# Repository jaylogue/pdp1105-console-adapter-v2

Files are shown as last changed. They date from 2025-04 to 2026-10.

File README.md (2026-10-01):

# PDP-11/05 Console Adapter

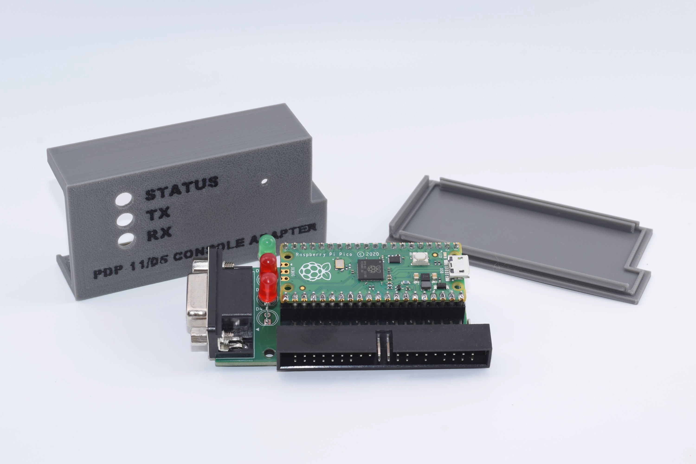
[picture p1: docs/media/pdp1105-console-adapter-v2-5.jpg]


The *PDP-11/05 Console Adapter* is a hardware device which acts as a USB and RS-232 serial interface to the console of a [PDP-11/05](http://gunkies.org/wiki/PDP-11/05) minicomputer. The Console Adapter provides a number of useful features for working with the PDP-11/05:

- **Direct connection to the SCL connector on the back of the PDP-11/05**
- **USB-to-serial functionality, allowing access to the PDP-11 console from a modern terminal program**
- **Auxiliary RS-232 interface for connecting a real serial terminal**
- **External baud clock generator, allowing console data rates greater than 2400 bps**
- **Dynamically adjustable serial data rate and format (110 to 38400 bps, 8-N-2, 7-E-2, 7-O-2)**
- **Virtual paper tape reader compatible with the 11/05's READER RUN signal**
- **M9312/M9301 console loader that can directly load data into the PDP-11's memory using console commands**

This version of the PDP-11/05 Console Adapter project (version 2) is based on the ubiquitous [Raspberry Pi Pico](https://www.raspberrypi.com/products/raspberry-pi-pico/) microcontroller. An earlier version based on the Teensy 3.2 microcontroller can be found [here](https://github.com/jaylogue/pdp-1105-console-usb-adapter).

### Project Status (2025/07/29)

The first major release of the PDP-11/05 Console Adapter is ready. The schematic and PCB designs are finished and final hardware has been built. The firmware is feature complete and tested, and user documentation has been written. Two different 3D-printed enclosures have been designed and built, and the design files for these are available for download.

I am happy to make assembled hardware or kits available to those enthusiasts who own real PDP-11/05 or /10 systems. Please reach out to me at jay DOT logue AT gmail DOT com for details.

<hr>

**[How it Works](#how-it-works)**<br>
&nbsp;&nbsp;&nbsp;&nbsp;&nbsp;&nbsp;&nbsp;&nbsp;**[Console Interface](#console-interface)**<br>
&nbsp;&nbsp;&nbsp;&nbsp;&nbsp;&nbsp;&nbsp;&nbsp;**[Auxiliary Terminal Interface](#auxiliary-terminal-interface)**<br>
&nbsp;&nbsp;&nbsp;&nbsp;&nbsp;&nbsp;&nbsp;&nbsp;**[Baud Clock Generation](#baud-clock-generation)**<br>
&nbsp;&nbsp;&nbsp;&nbsp;&nbsp;&nbsp;&nbsp;&nbsp;**[Host Selectable Data Rate / Serial Format](#host-selectable-data-rate--serial-format)**<br>
&nbsp;&nbsp;&nbsp;&nbsp;&nbsp;&nbsp;&nbsp;&nbsp;**[Status LEDs](#status-leds)**<br>
&nbsp;&nbsp;&nbsp;&nbsp;&nbsp;&nbsp;&nbsp;&nbsp;**[Power Source](#power-source)**<br>
&nbsp;&nbsp;&nbsp;&nbsp;&nbsp;&nbsp;&nbsp;&nbsp;**[Virtual Paper Tape Reader](#virtual-paper-tape-reader)**<br>
&nbsp;&nbsp;&nbsp;&nbsp;&nbsp;&nbsp;&nbsp;&nbsp;**[M9312/M9301 Console Loader](#m9312m9301-console-loader)**<br>
&nbsp;&nbsp;&nbsp;&nbsp;&nbsp;&nbsp;&nbsp;&nbsp;**[On-device File Library](#on-device-file-library)**<br>
&nbsp;&nbsp;&nbsp;&nbsp;&nbsp;&nbsp;&nbsp;&nbsp;**[XMODEM File Upload](#xmodem-file-upload)**<br>
**[Schematic](#schematic)**<br>
**[PCB Design Files](#pcb-design-files)**<br>
**[3D Printable Cases](#3d-printable-cases)**<br>
**[User Documentation](#user-documentation)**<br>
**[License](#license)**<br>

## How it Works

### Console Interface

At the most basic level, the Console Adapter operates as a TTL-serial interface, connecting the PDP-11's console (also known as the Serial Communication Line or SCL port) to one of the Pico's internal UARTs. Level shifting circuitry in the adapter adjusts the PDP's 5V outputs to match the Pico's 3.3V inputs. Using USB software on the Pico, the adapter appears as a virtual COM port when connected to a host computer via USB, making it possible to use a standard terminal program (e.g. minicom, picocom or PuTTY) to interact with the PDP's console. In this way, the Console Adapter operates very similarly to an off-the-shelf USB-to-TTL serial device, with the exception that its behavior is fully customizable in software.

The Console Adapter supports standard serial data rates in the range accepted by the PDP-11 (110 to 38400 bps). Internally, the CPU in the PDP-11/05 is hard-wired to use the 8-N-2 serial format. However, with appropriate software support on the PDP side, 7-E-2 or 7-O-2 formats can also be used (other formats are not supported). Based on this, the Console Adapter limits the SCL format to one of these three combinations.

### Baud Clock Generation

The PDP-11/05 CPU includes a clock generator circuit which is used to generate the 16X clock signal needed to drive the internal console UART chip. Due to its simplicity, the internal generator limits the maximum usable data rate to 2400 bps. Conveniently, the PDP-11/05 provides a way to override the internal generator by providing an external clock signal on the SCL port. This allows the console to run at substantially higher data rates (theoretically up to 40000 bps).

To enable higher data rates, the Console Adapter employs a PWM peripheral on the Pico to generate the necessary clock signal to drive the PDP's UART. The frequency of this clock signal is automatically adjusted to match the data rate of the Pico's UART, ensuring that the two systems are always in sync.

### Auxiliary Terminal Interface

In addition to the host USB interface, the Console Adapter provides a second interface which can be used to connect a traditional serial terminal such as a VT-100. An RS-232 level shifter (MAX3232) is used to convert the signals to standard EIA levels, allowing most terminals of the era to be used. When connected, the terminal functions as an additional console for the PDP-11.

An auxiliary terminal can be used in parallel with a terminal program connected via USB. When operated this way, characters typed on either the host computer or the auxiliary terminal are forwarded to the PDP-11, while characters output by the PDP-11 appear simultaneously on both terminals. It is also possible to use the Console Adapter with just an auxiliary terminal connected (i.e. without a host USB connection).

The data rate and serial format for the auxiliary terminal can be set independently from that of the PDP-11's SCL port. (Although, since neither interface supports flow control, it is best to keep the data rates the same or similar between the two.)

### Host Selectable Data Rate / Serial Format

The Console Adapter appears to the host computer as a standard USB COM device. As such, it is able to receive and process standard USB requests to change the serial configuration (also known as CDC Line Coding requests). This makes it possible to adjust the adapter's serial data rate and format directly from within terminal software running on the host.

When the Console Adapter receives a Line Coding request it adjusts the configuration of the console UART and baud clock generator to match the requested data rate and serial format. Serial configuration changes happen on the fly and can be made at any time. If desired, the auxiliary terminal interface can also be set to automatically adjust to the new configuration.

The PDP-11/05's SCL port is hard-wired to use 2 stop bits. This format is somewhat unusual in modern systems, and most terminal programs default to a format using 1 stop bit (usually 8-N-1). As a convenience to the user, the Console Adapter accepts USB Line Coding requests for 1 stop bit formats and internally translates them into the equivalent 2 stop bit format when configuring the SCL port.

The choice to dynamically adjust the serial configuration based on a request from the host can be enabled or disabled independently for both the SCL and auxiliary terminal ports. When this feature is disabled, the serial configuration is controlled by a setting in the Console Adapter's settings menu. These settings are persisted in flash and survive adapter reboots.

### Status LEDs

The PDP-11/05 Console Adapter has three status LEDs:

- **Power/Activity LED**: Lit while the system is powered. Flashes briefly whenever there is activity in the Console Adapter.
- **TX and RX LEDs**: Normally off. Flash on whenever characters are transmitted/received by the PDP-11.

Additionally, the Pico's onboard LED mimics the behavior of the Power/Activity LED.

### Power Source

The Console Adapter operates on +5 volts, which it can receive either from the PDP-11/05 itself or via the USB port. Because the Console Adapter can get its power directly from the PDP, it is possible to use the Console Adapter with only an auxiliary terminal connected.

Both power sources can be active at the same time, and the USB port can be connected or disconnected on the fly. (However, **_do not_** hot plug/unplug the Console Adapter to the 11/05's SCL port, as it is not designed to support this.)

### Virtual Paper Tape Reader

The PDP-11/05 SCL port includes a signal called "READER RUN" which is designed to drive a low-speed paper tape reader attached to the console device (the quintessential example being the [ASR-33 teletype](https://en.wikipedia.org/wiki/Teletype_Model_33)). Whenever the PDP asserts the "READER RUN" signal, the reader is expected to read one character from a mounted paper tape and send it to the computer. In the Console Adapter, the READER RUN signal drives a transistor whose output is fed to a GPIO pin on the Pico. Software on the Pico detects READER RUN transitions and uses this to emulate the behavior of a legacy tape reader.

Users can mount paper tape images on the virtual paper tape reader using the Console Adapter's menu system (accessed by typing a special _menu_ key on the console). While the tape reader is active, a visual progress bar is displayed showing how much of the tape image has been read. Virtual tapes are unmounted automatically when the end of the tape is reached, or can be unmounted manually via the UI.

### M9312/M9301 Console Loader

On systems equipped with an M9312 or M9301 Bootstrap Terminator module, the PDP-11/05 Console Adapter can be used to load data files directly into the PDP's memory using the UI provided by the module's console ROM. Data is loaded by issuing a series of Load Address (L) and Deposit (D) commands and monitoring the responses received from the console. The loader automatically detects data files in Absolute Loader (LDA) format and arranges to load their contents at the correct memory offsets.

The loader includes special support for loading the PDP-11 Bootstrap Loader (the code for which is built into the Console Adapter firmware). When requested to load the Bootstrap Loader, the Console Adapter will prompt the user for the memory size of the machine and adjust the software's load address and instruction contents automatically, following the rules described in the associated DEC documentation.

A similar feature is available for loading the Absolute Loader, which allows for bypassing the Bootstrap Loader step completely.

### On-device File Library

The Console Adapter supports the ability to load frequently used paper tape images and other types of data files into the Pico's flash memory such that they are readily available for use when working with the PDP-11. A Python-based command line tool is provided that gathers a set of data files into a .uf2 file which can then be written to flash using one of the standard Pico firmware update processes (e.g. by dragging it onto the Pico's virtual disk). Once programmed in flash, files in the library are available for mounting on the virtual paper tape reader, or loading directly into memory using the M9312/M9301 console loader feature.

1MiB of flash memory is available for file storage. Up to 36 files may be stored in this memory, with each file limited to a maximum of 128KiB.

### XMODEM File Upload

In addition to files stored in flash, data files can be uploaded to the Console Adapter using the XMODEM file transfer protocol. Files can be uploaded either via the USB interface or the auxiliary terminal interface using appropriate XMODEM software on the sending side. Once uploaded, a file can be used repeatedly for mounting on the virtual paper tape reader or loading via the console loader.

Uploaded files are stored in RAM on the Console Adapter and are limited to 64KiB in size.

## Schematic

The following diagram shows the schematic for the PDP-11/05 Console Adapter:

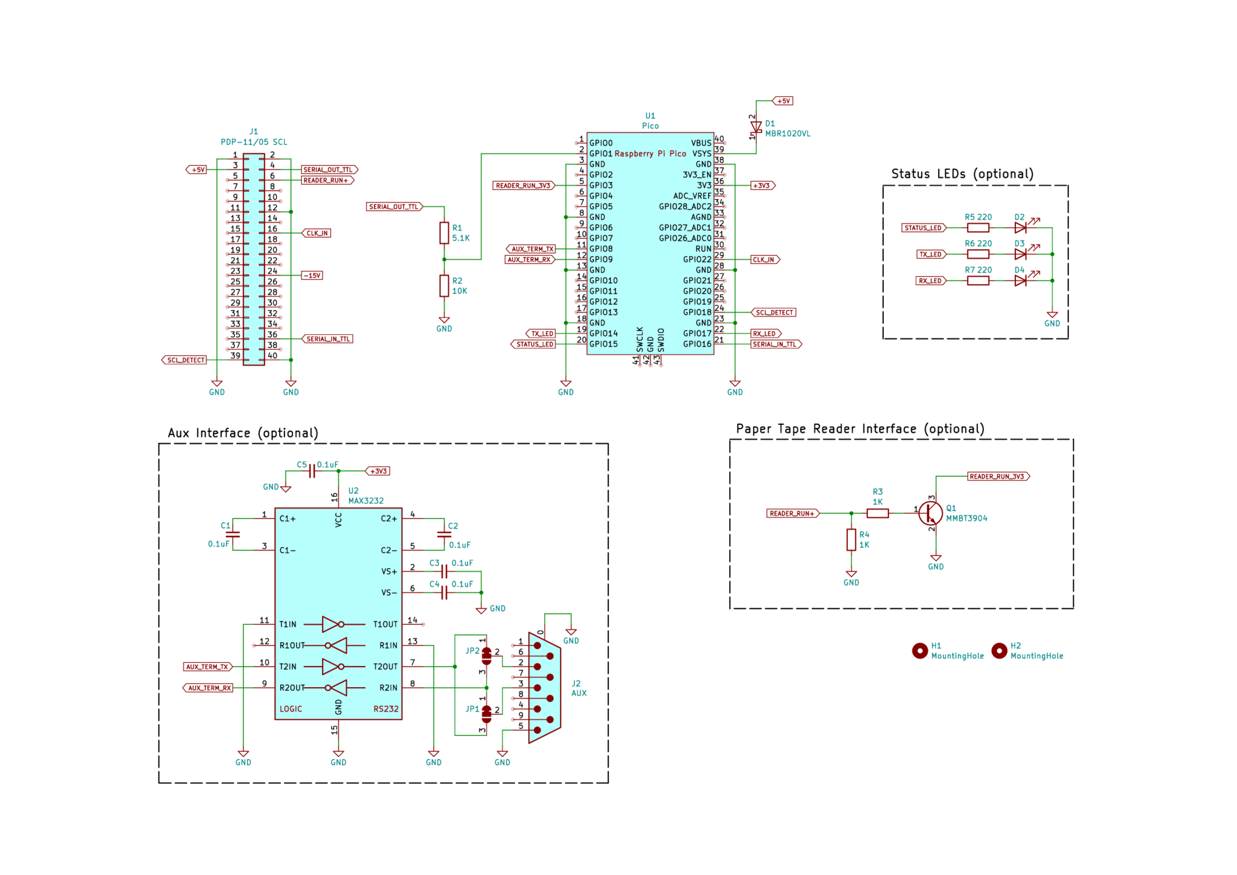
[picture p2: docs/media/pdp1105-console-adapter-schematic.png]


A PDF version of the schematic is available [here](docs/pdp1105-console-adapter-schematic.pdf).

Note that the Console Adapter schematic uses modern pin numbering for the console IDC connector (J1), rather than the archaic DEC letter-based scheme. For a table showing the relationship between the two numbering schemes, see the following PDF: [pdp1105-scl-connector.pdf](docs/pdp1105-scl-connector.pdf).

## PCB Design Files

A KiCad project containing the schematic and a layout file for a two-layer PCB is available in the [pcb](pcb) folder.

## 3D Printable Cases

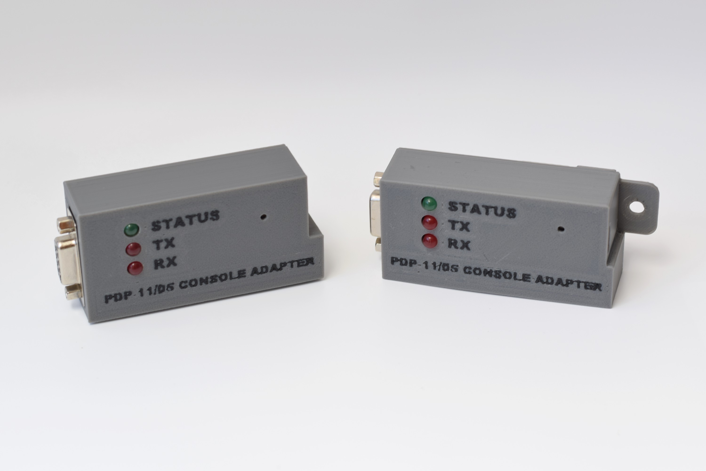
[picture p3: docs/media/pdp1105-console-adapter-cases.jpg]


The [case](case) folder contains model and design files for a set of 3D-printable cases for the Console Adapter. Two case styles are provided: a **standalone case** and a **direct attach case**. Each style consists of a bottom 'base' piece and a top 'cover' piece. The lettering visible on the case is embossed into the top piece. A separate design file is included which allows this lettering to be filled with a different color on printers that support swapping filaments.



The standalone case allows the Console Adapter to be connected to the PDP-11/05 using a ribbon cable. A hole on the side of the case accommodates a right-angle 40-pin male IDC connector, which is mounted on the top of the PCB. The two halves of the standalone case snap together, holding the PCB in place.

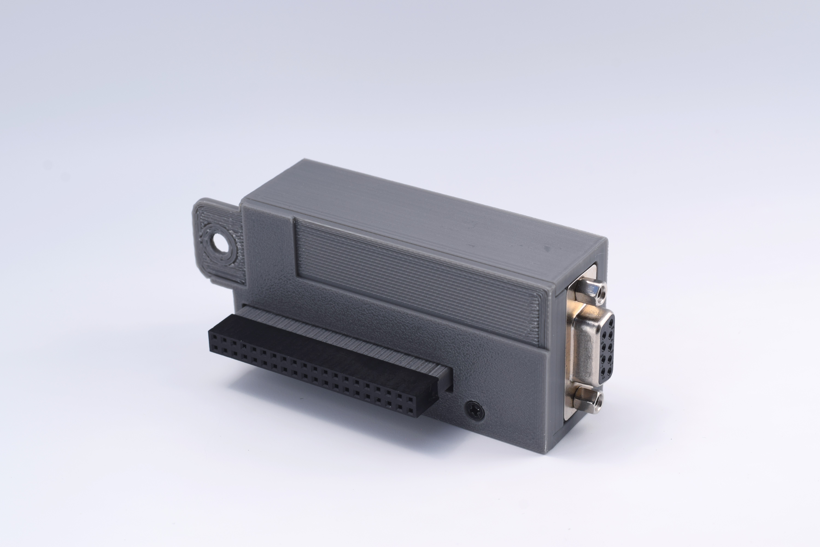
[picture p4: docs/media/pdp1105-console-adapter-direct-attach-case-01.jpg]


The direct attach case has a hole on the bottom of the case through which a female 40-pin connector protrudes. The connector is soldered to the bottom of the PCB, and extends from the back of the case far enough to allow the adapter to plug directly into the PDP's SCL port. A flange with a screw hole allows the case to be anchored to the back of the system using an existing case screw.

The direct attach case is held together with two small screws which pass through the PCB.

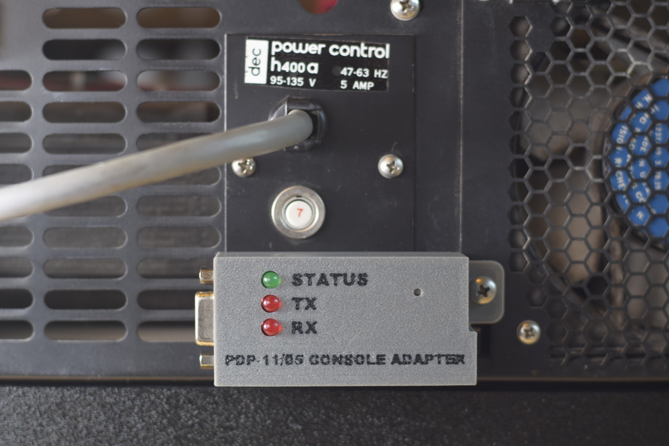
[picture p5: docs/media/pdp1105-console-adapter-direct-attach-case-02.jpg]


## User Documentation

A User Manual for the PDP-11/05 Console Adapter is available [here](docs/pdp1105-console-adapter-user-manual.md).

## License

The PDP-11/05 Console Adapter source code is licensed under the [Apache version 2.0 license](https://www.apache.org/licenses/LICENSE-2.0).

Other content, including all documentation, images, schematics, PCB and case designs, and this README file, is licensed under a [Creative Commons Attribution 4.0 International License](https://creativecommons.org/licenses/by/4.0/).

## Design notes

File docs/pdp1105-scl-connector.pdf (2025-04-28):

# PDP-11/05 SCL Connector

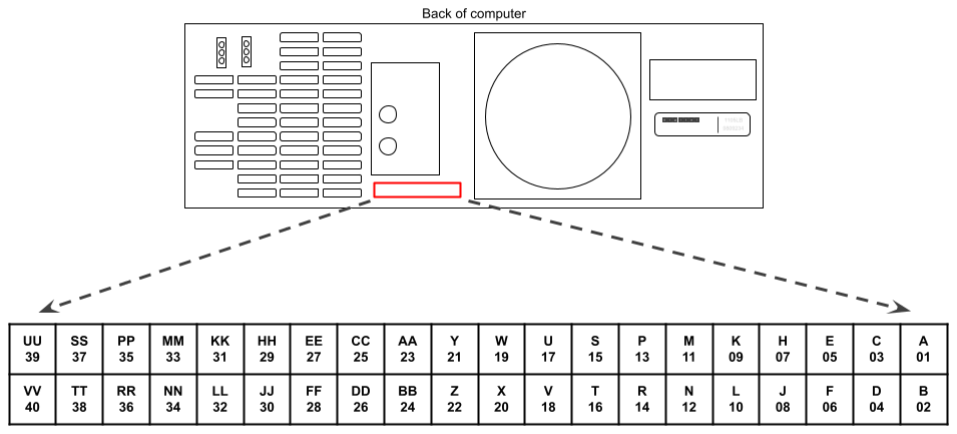
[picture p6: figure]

## SCL Connector Signals

Signal | SCL Connector Pin
GND | A/01, B/02, UU/39, VV/40
-15V | BB/24
SERIAL OUT + (20mA) | V/18
CLK IN (TTL) | T/16
SERIAL IN - (20mA) | DD/26
READER RUN - (20mA) | R/14
CLK DISAB (TTL) | N/12
SERIAL OUT - (20mA) | L/10
+5V | C/03
SERIAL OUT (TTL) | D/04
READER RUN + (20mA) | F/06
SERIAL IN (TTL) * | RR/36
20ma INTERLOCK ** | NN/34
SERIAL IN + (20ma) | LL/32

## Notes

* SERIAL IN (TTL) [RR/36] expects the input signal to be inverted as compared to a traditional TTL serial line--i.e. 0V represents a serial MARK and +5V represents a SPACE.

** To enable the 20ma interface, 20ma INTERLOCK [NN/34] must be connected to SERIAL IN (TTL) [RR/36].

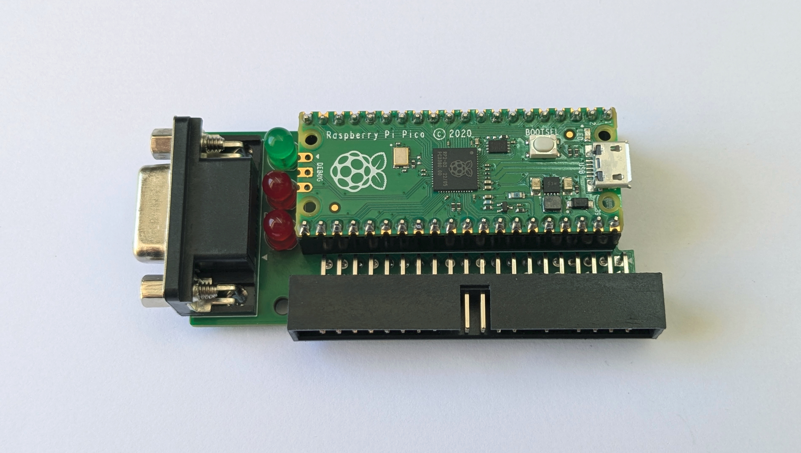
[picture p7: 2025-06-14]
docs/media/pdp1105-console-adapter-v2-3.jpg

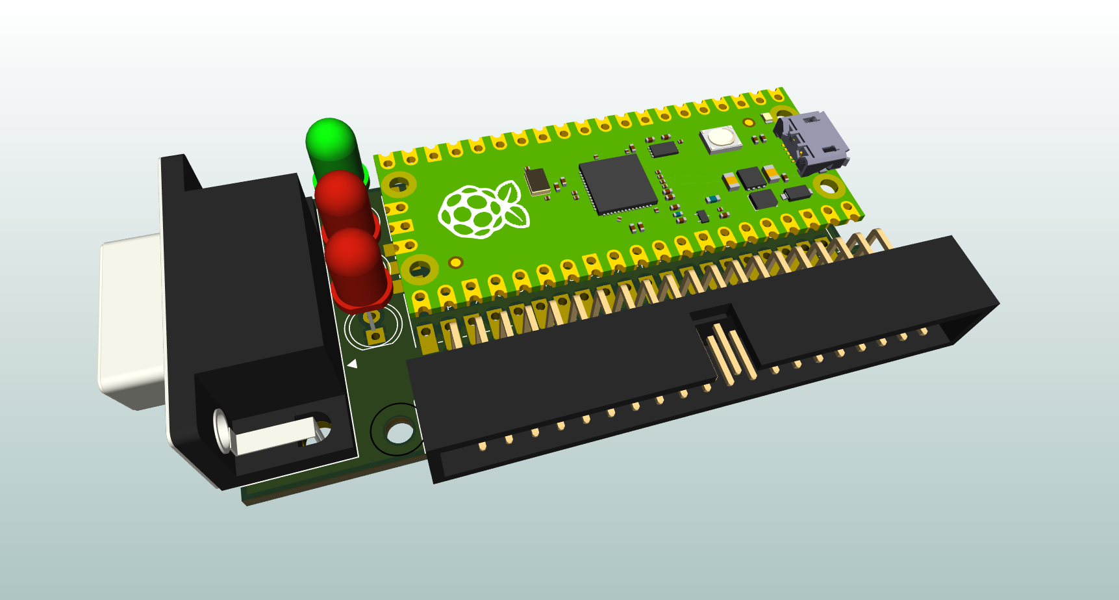
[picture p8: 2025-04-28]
docs/media/pdp1105-console-adapter-v2.png

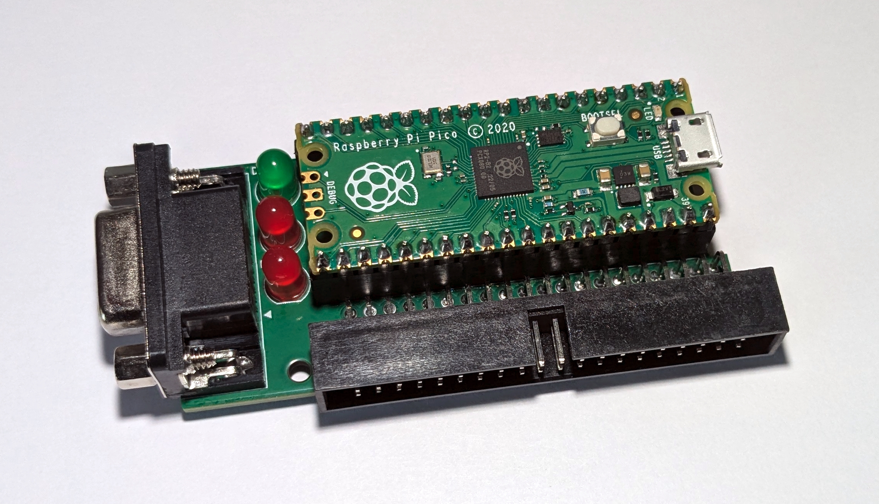
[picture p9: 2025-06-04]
docs/media/pdp1105-console-adapter-v2-2.jpg

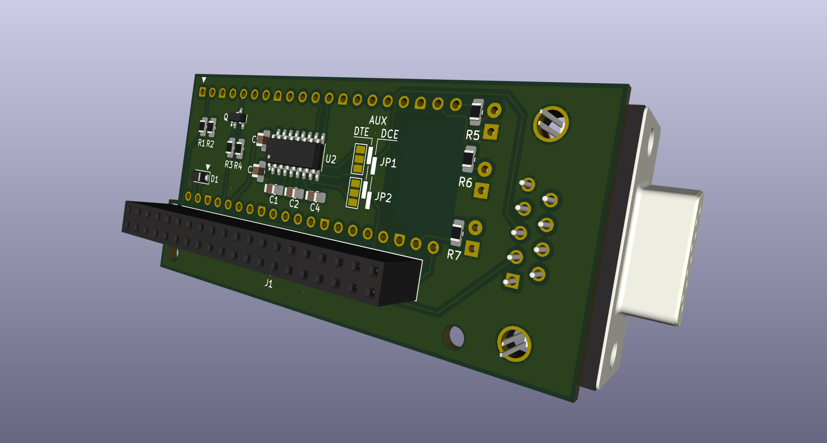
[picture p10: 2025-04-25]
pcb/pdp1105-console-adapter-v2-pcb-3d-perspective-back.png

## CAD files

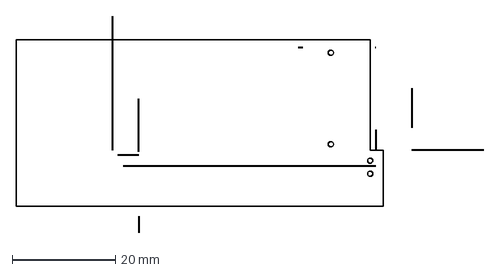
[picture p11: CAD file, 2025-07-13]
case/DXF/pdp1105-console-adapter-v2-board-outline.dxf
90.8 x 42.0 mm

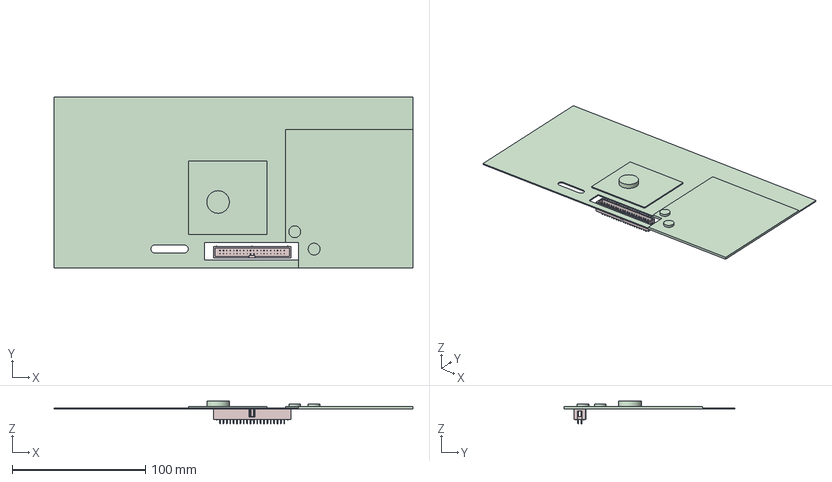
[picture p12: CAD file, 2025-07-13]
case/STEP/pdp1105-console-adapter-v2-case-mock.step
269.9 x 128.6 x 17.1 mm
PDP 11-05
IDC-Header_2x20_P2.54mm_Vertical

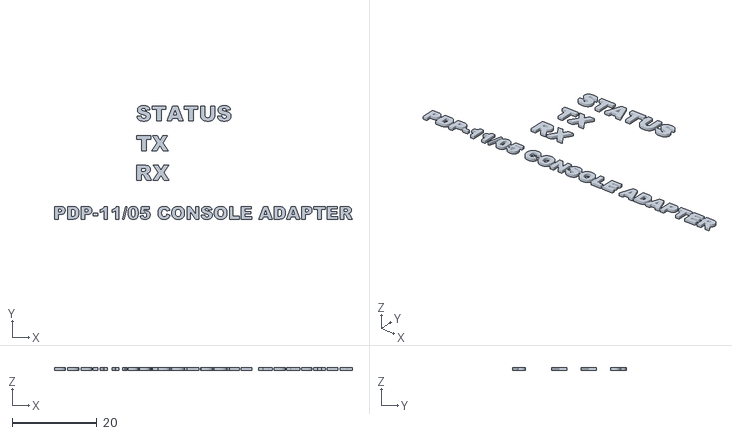
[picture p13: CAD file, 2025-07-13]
case/STL/pdp1105-console-adapter-v2-direct-attach-case-embossed-text.stl
70.3 x 26.9 x 0.6

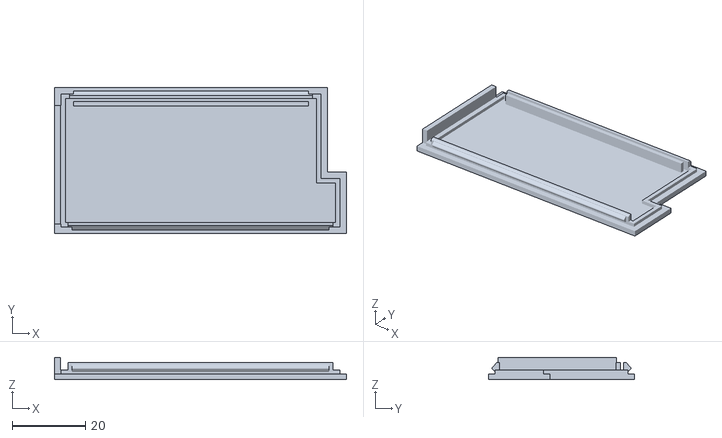
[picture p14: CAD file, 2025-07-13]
case/STL/pdp1105-console-adapter-v2-standalone-case-bottom.stl
79.5 x 39.8 x 6.06

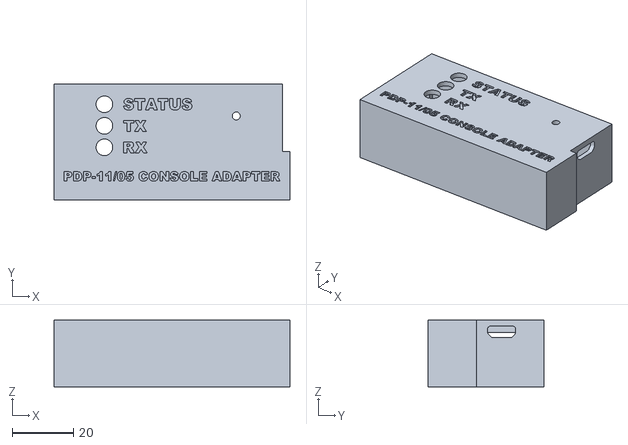
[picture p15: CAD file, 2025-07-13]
case/STL/pdp1105-console-adapter-v2-direct-attach-case-top.stl
76.8 x 37.8 x 21.7

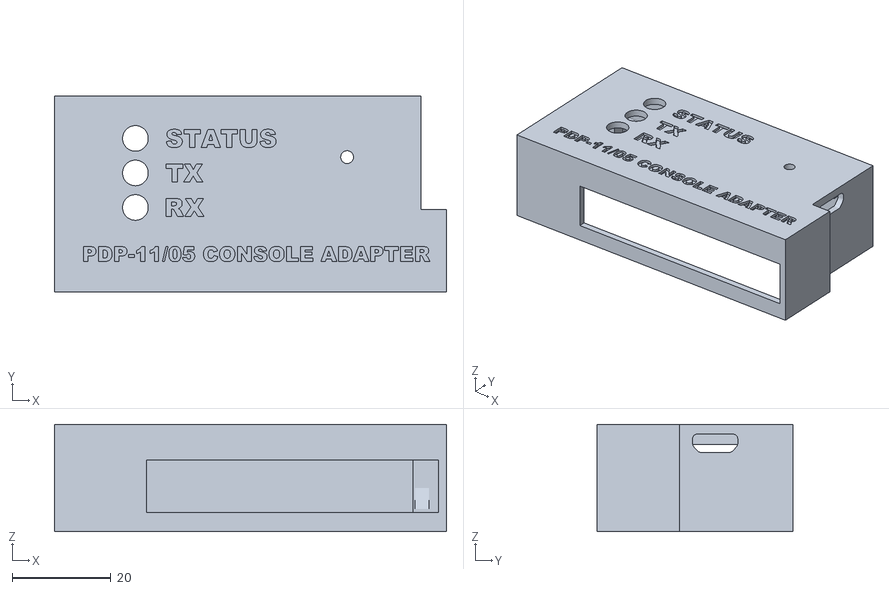
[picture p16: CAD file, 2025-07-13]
case/STL/pdp1105-console-adapter-v2-standalone-case-top.stl
79.5 x 39.8 x 21.7

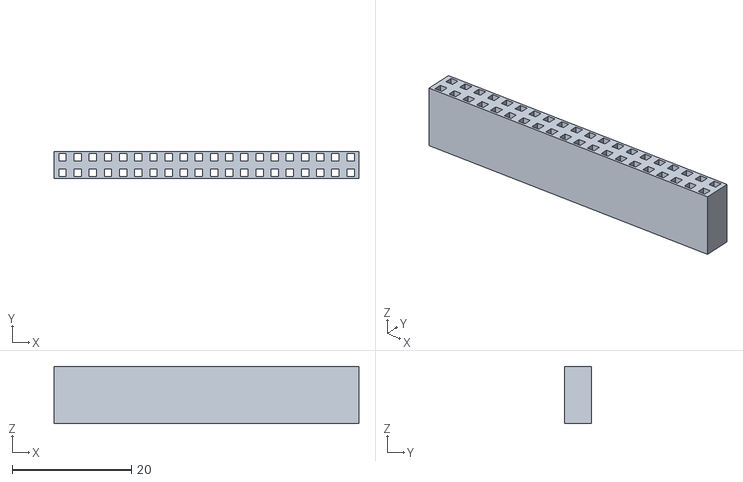
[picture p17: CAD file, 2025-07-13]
case/STL/pdp1105-console-adapter-v2-direct-attach-case-spacer.stl
51.1 x 4.58 x 9.60

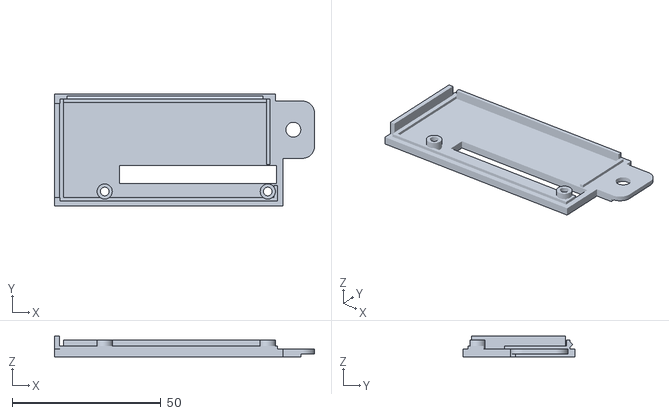
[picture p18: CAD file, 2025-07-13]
case/STL/pdp1105-console-adapter-v2-direct-attach-case-bottom.stl
87.5 x 37.8 x 6.95

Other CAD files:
case/STL/pdp1105-console-adapter-v2-standalone-case-embossed-text.stl

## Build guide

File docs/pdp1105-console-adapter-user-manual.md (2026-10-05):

# PDP-11/05 Console Adapter User Manual

- [Introduction](#introduction)
- [Hardware Overview](#hardware-overview)
  - [Interface Ports](#interface-ports)
  - [Status LEDs](#status-leds)
- [Initial Setup](#initial-setup)
  - [Powering the Console Adapter](#powering-the-console-adapter)
  - [Connecting the Console Adapter to a PDP-11/05](#connecting-the-console-adapter-to-a-pdp-1105)
  - [Connecting to a USB Host Computer](#connecting-to-a-usb-host-computer)
  - [Connecting an Auxiliary Terminal](#connecting-an-auxiliary-terminal)
  - [Performing a Loop-back Test](#performing-a-loop-back-test)
  - [Updating the Console Adapter Firmware](#updating-the-console-adapter-firmware)
- [Basic Operation](#basic-operation)
  - [Terminal Mode](#terminal-mode)
  - [Menu Mode](#menu-mode)
  - [Transparent Mode](#transparent-mode)
- [Virtual Paper Tape Reader](#virtual-paper-tape-reader)
  - [Mounting a Paper Tape Image](#mounting-a-paper-tape-image)
  - [Unmounting a Paper Tape Image](#unmounting-a-paper-tape-image)
  - [Viewing Status of the Paper Tape Reader](#viewing-status-of-the-paper-tape-reader)
- [M9312/M9301 Console Loader](#m9312m9301-console-loader)
  - [Loading Absolute Loader (LDA) Files](#loading-absolute-loader-lda-files)
  - [Loading Simple Data Files](#loading-simple-data-files)
  - [Loading the Bootstrap Loader](#loading-the-bootstrap-loader)
  - [Loading the Absolute Loader](#loading-the-absolute-loader)
- [Adapter Settings](#adapter-settings)
  - [Changing the SCL Port Configuration](#changing-the-scl-port-configuration)
  - [Default SCL Port Configuration](#default-scl-port-configuration)
  - [Changing the AUX Port Configuration](#changing-the-aux-port-configuration)
  - [Controlling the Paper Tape Progress Bar](#controlling-the-paper-tape-progress-bar)
  - [Enabling/Disabling Uppercase Mode](#enablingdisabling-uppercase-mode)
- [Adapter Status](#adapter-status)
- [Flash File Library](#flash-file-library)
  - [Creating a File Library Image](#creating-a-file-library-image)
  - [Flashing a New File Library](#flashing-a-new-file-library)
- [Copyright](#copyright)

---

## Introduction

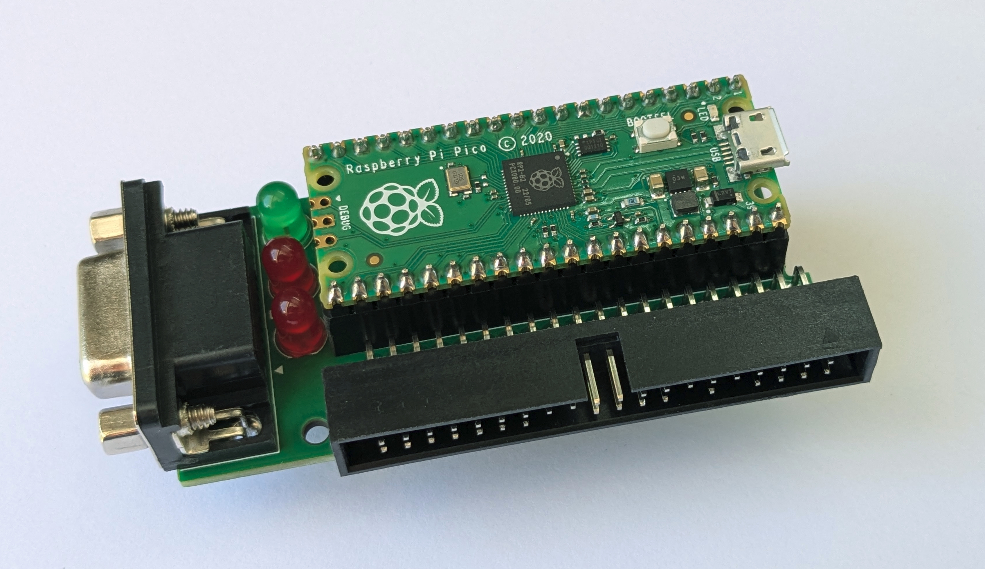
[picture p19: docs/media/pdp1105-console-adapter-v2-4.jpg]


The PDP-11/05 Console Adapter is a serial interface adapter for the console of a [PDP-11/05](http://gunkies.org/wiki/PDP-11/05) minicomputer. It connects to the PDP-11's Serial Communication Line (SCL) port and makes it possible to communicate with the system over USB, using a terminal program running on a host computer. It also supports connecting a traditional RS-232 terminal.

## Hardware Overview

The Console Adapter hardware consists of a Raspberry Pi Pico microcontroller, a MAX3232 RS-232 driver/receiver and a small amount of support circuitry. Most of the functionality of the Console Adapter is embodied in the Pico microcontroller. The remaining circuitry is largely concerned with adapting the Pico to the voltage levels used by the PDP-11 and external terminals.

### Interface Ports



The Console Adapter has three primary interfaces:

- **USB port**: A female micro-USB connector for connecting to a host computer (located on the Pico microcontroller PCB).
- **SCL port**: A 40-pin IDC connector for connecting to the PDP-11/05's SCL port.
- **AUX port**: A female DE-9 connector for connecting an auxiliary RS-232 terminal.

Use of either the USB or AUX ports is optional.

### Status LEDs

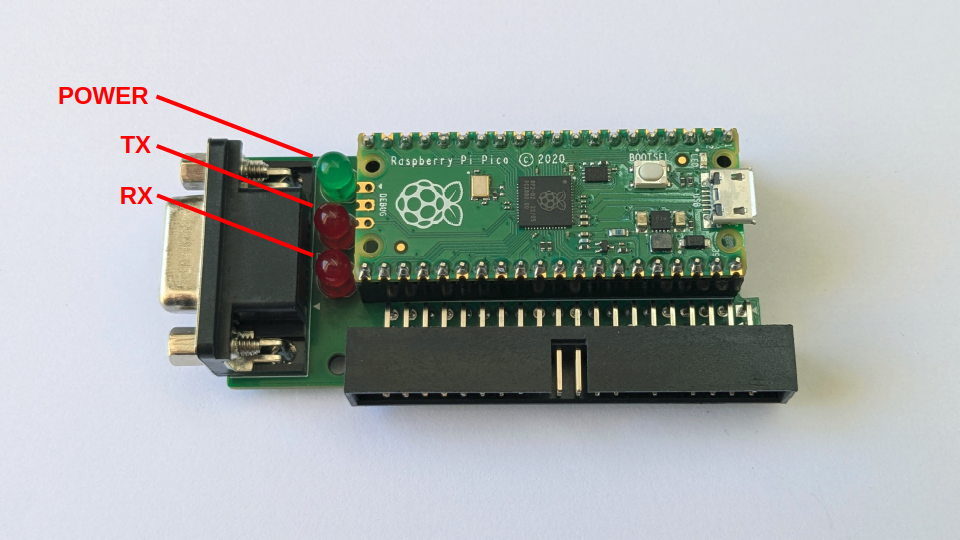
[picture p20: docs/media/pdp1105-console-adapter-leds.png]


The PDP-11/05 Console Adapter has three LEDs that show the status and activity of the system:

- **Power/Activity LED**: Lit while the system is powered. Flashes briefly whenever there is activity in the Console Adapter.
- **TX and RX LEDs**: Normally off. Flash on whenever characters are transmitted/received by the PDP-11.

Additionally, the Pico's onboard LED mimics the behavior of the Power/Activity LED.

## Initial Setup

### Powering the Console Adapter

The Console Adapter operates on +5 volts. The adapter can receive power either directly from the PDP-11/05 or via a USB connection to a host computer. Both power sources can be active at the same time, and the USB port can be connected or disconnected on the fly while the adapter is connected to the PDP-11.

_**CAUTION**: Do not hot plug/unplug the Console Adapter to the PDP-11. It is not designed to support this._

_**CAUTION**: The Console Adapter is not internally isolated. As a consequence, when the adapter is connected to both the PDP-11 and a host computer via USB, the grounds of the two systems are electrically connected. To avoid ground potential differences, ensure that both the PDP and the host computer are connected to the same power circuit and that both systems are suitably earth grounded._

### Connecting the Console Adapter to a PDP-11/05

The Console Adapter must be connected to the PDP-11/05 using a 40-pin ribbon cable with 2x20 pin IDC connectors at each end. Generally speaking, this cable should be as short as possible, for signal integrity reasons. However, cables up to 6 ft (2 m) will probably work fine.

The SCL port on the PDP-11/05 predates modern connector standards. As such, it lacks the slot needed to accept the square registration "key" present on most modern ribbon cable connectors. Because of this, it is necessary to file off the registration key on one connector when making an SCL cable out of modern components.

_**CAUTION**: The lack of the registration key on the SCL connector means that it is possible to connect the SCL cable to the PDP-11 in the wrong orientation. Therefore, **be especially careful to orient the SCL cable correctly when connecting it to the PDP-11**. In particular, the SCL cable connector should be positioned such that **pin 1 is towards the right-hand side of the PDP-11** when looking at the system from behind. On most ribbon cables, pin 1 can be identified by the presence of a small triangle on one side of the connector, or by the red stripe on one edge of the ribbon cable._

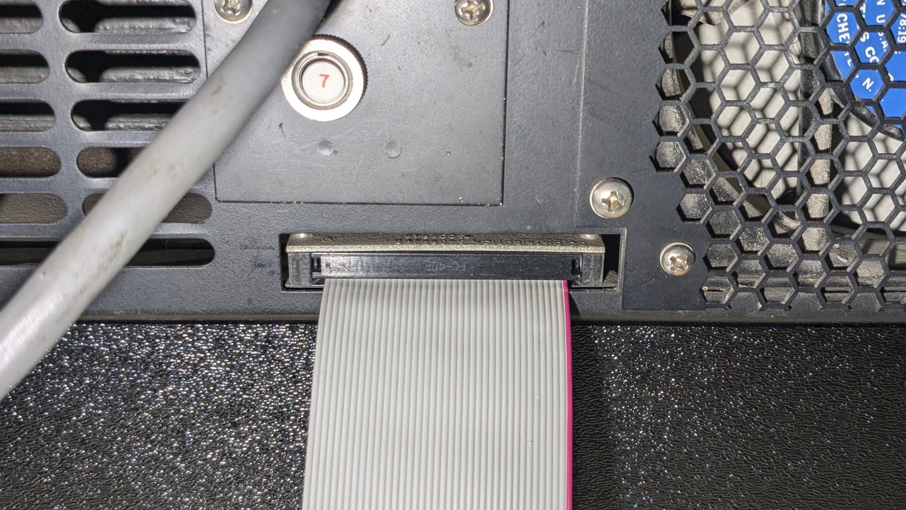
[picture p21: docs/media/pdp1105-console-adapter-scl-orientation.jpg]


### Connecting to a USB Host Computer

The primary means of interacting with the Console Adapter is via a USB connection to a host computer. This requires a cable with a micro-USB connector on one end and either a USB A or USB C connector on the other end.

When connected via USB the Console Adapter appears as a virtual COM device on the host computer. To connect a terminal emulator to the COM device one must know the OS-specific device name, which varies depending on what other devices are connected to the computer.

The following commands can be used to find the device name of the Console Adapter device:

- **Windows**:
  ```powershell
  powershell "Get-WmiObject Win32_SerialPort | Where-Object { $_.PNPDeviceID -match 'VID_2E8A' } | Select-Object DeviceID"
  ```

- **Linux**:
  ```bash
  ls -1 /dev/tty* | while read d; do [[ $(udevadm info $d | grep -i VENDOR_ID=2e8a) ]] && echo $d; done
  ```

- **macOS**:
  ```bash
  ioreg -rxlc IOUSBHostDevice | perl -ne '/"idVendor" = (.+)/ && ($v=$1); /"IOCalloutDevice" = "(.+)"/ && print "$1\n" if($v==11914)'
  ```

Once the device name is known, a terminal emulator program can be used to interact with the Console Adapter. Commonly used serial terminal programs include PuTTY (Windows), minicom (Linux, macOS), picocom (Linux, macOS), Serial (macOS) and ZOC (macOS).

When initially connecting a terminal program to the Console Adapter, it is suggested to set the program's serial configuration to 9600 bps, 8 data bits, no parity, 1 stop bit. This gives reasonable performance while being generally well supported by software running on the PDP-11.

Note that, for USB COM devices like the Console Adapter, the serial configuration set in the terminal program does not actually affect the way characters are communicated over the USB connection. Rather, changes to the serial configuration are forwarded over the USB connection to the USB device itself, where they are used to adjust the configuration of the serial link between the device and whatever system it is connected to. In the case of the Console Adapter, changing the configuration in the terminal program results in an adjustment to the serial configuration of the SCL port.

### Connecting an Auxiliary Terminal

It is possible to connect a standard RS-232 terminal (such as a classic DEC VT102) to the Console Adapter via its AUX port. An auxiliary terminal can be used in addition to, or instead of, a terminal emulator connected via the USB port.

The Console Adapter's AUX port uses a standard DE-9 female connector, with connections for Transmit Data (TD), Receive Data (RD) and Ground (GND). There is no support for hardware flow control signals (as is typical of DEC serial ports of the era).

By default, the AUX port is configured as a DCE device, making it possible to use a standard "straight-through" serial cable when connecting the Console Adapter to most terminals.

A typical auxiliary terminal cable would be wired as follows:

| Terminal End<br/>(DB25 -M or -F) | Console Adapter End<br/>(DE-9-M) | Signal |
|:-----:|:-----:|:-----:|
| 2 | 3 | TD  |
| 3 | 2 | RD  |
| 7 | 5 | GND |

If needed, the AUX port can be converted to DTE configuration by changing jumpers JP1 and JP2 located on the underside of the Console Adapter PCB. This requires cutting the traces between pads 1 and 2 on both jumpers and creating a solder bridge between the other two pads.

Note that, while this change is straightforward to do, it is likely easier to use a null-modem adapter, or a cable with null-modem wiring.

_**CAUTION**: An early revision of the Console Adapter PCB (rev 4.1) contains an error in the silkscreen labeling for JP1 and JP2. On these boards, the AUX DTE/DCE jumper positions are **opposite** to what is shown on the PCB. You can identify an old board by the positioning of the words on the silkscreen: "DCE" will be on the left, and "DTE" will be on the right. In actuality, these labels should be reversed._

### Performing a Loop-back Test

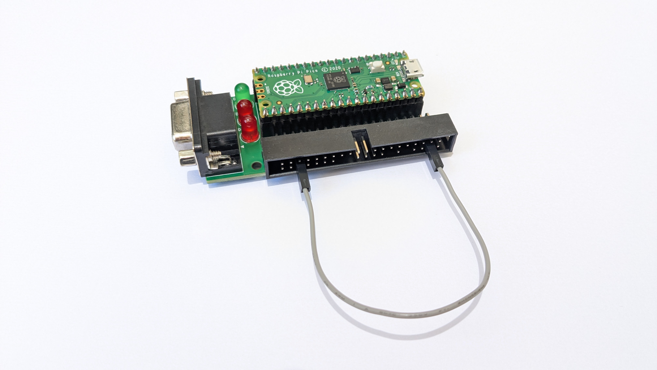
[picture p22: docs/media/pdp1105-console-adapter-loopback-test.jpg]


To validate the functionality of the Console Adapter a simple loopback test can be performed while the adapter is disconnected from the PDP-11. This requires the use of a short jumper wire with female pin connectors (sometimes called DuPont or Berg connectors) on each end.

- With the Console Adapter disconnected from the PDP-11, connect together **pin 4 and pin 36** on the SCL port connector.
- Plug the adapter into a host computer via USB.
- Start a terminal emulator program on the host computer and connect it to the Console Adapter.
- Type characters into the terminal program and observe that the characters are echoed back correctly.
- [Optional] Connect an auxiliary terminal to the AUX port, configured with the correct serial settings. Verify correct echoing of characters via the auxiliary terminal.

### Updating the Console Adapter Firmware

The Console Adapter firmware can be updated by following the standard procedure for updating firmware on a Raspberry Pi Pico:

- Start with the Console Adapter in a powered-off state by powering off the PDP-11 (if attached) and disconnecting the USB connection to the host computer.
- While holding down the BOOTSEL button on the Pico, plug in the USB cable to the host computer.
- When the Pico virtual drive appears on the host computer (look for a drive named "RPI-RP2"), drag or copy the firmware image file (typically pdp1105-console-adapter.uf2) onto the drive.
- After a moment, the virtual drive will disappear and the Console Adapter will reboot.
- Once the device finishes booting, the new firmware is installed and ready for use.

Note that it is also possible to update the Console Adapter firmware using the Raspberry Pi [picotool](https://github.com/raspberrypi/picotool) command-line tool. This approach can be more convenient in that it does not require pressing the BOOTSEL button. Prebuilt binaries for the picotool command are available online at the [Pico SDK Tools](https://github.com/raspberrypi/pico-sdk-tools) GitHub page.

To update the Console Adapter firmware using the picotool command, perform the following steps:

- Connect the Console Adapter to a host computer using a USB cable.
- At a command prompt, run the picotool command as follows, passing the pathname of the firmware image to be installed:
  ```bash
  picotool load output/pdp1105-console-adapter.uf2 -f
  ```
- After the command finishes, the Console Adapter will reboot. When finished the new firmware is installed and ready for use.

## Basic Operation

### Terminal Mode

Upon boot, the Console Adapter automatically enters **Terminal Mode**. In Terminal Mode, the adapter continuously relays characters between the USB port and the PDP-11's SCL port: any characters input by the user via a terminal program on the host are sent to the PDP-11, and any characters output by the PDP-11 are displayed in the terminal program.

If an auxiliary terminal is connected to the AUX port, the adapter will also relay characters between the auxiliary terminal and the PDP-11. The USB and AUX ports can both be used simultaneously, and any characters output by the PDP-11 will be shown on both.

By default, most characters are relayed without modification between the USB and AUX ports and the PDP-11's SCL port. An exception to this is the menu key which is used to invoke Menu Mode (see below). Additionally, a special mode can be enabled that forces all characters sent to the PDP-11 to be uppercase (see [Enabling/Disabling Uppercase Mode](#enablingdisabling-uppercase-mode)).

### Menu Mode

**Menu Mode** provides access to the various features of the Console Adapter, including mounting and unmounting virtual paper tapes, loading files via the M9312/M9301 console, changing adapter settings and viewing adapter status.

To enter Menu Mode from Terminal Mode press the menu key: `CTRL+^` (Control Shift 6). Upon entering Menu Mode, the adapter displays the Main Menu:

```
*** MAIN MENU:
  m) Mount paper tape           l) Load file using M93xx console
  u) Unmount paper tape         S) Adapter settings
  s) Adapter status             v) Adapter version
  -----
  ESC) Return to terminal mode  T) Enter transparent mode
  CTRL+^) Send menu character

>>> 
```

While in Menu Mode, requests for user input are indicated by a `>>>` prompt. Menu choices are made by pressing the single (case sensitive) key shown before each menu option.

In most contexts, pressing `ESC` or `CTRL+C` will exit Menu Mode and return the adapter to Terminal Mode.

Pressing `CTRL+^` from the Main Menu will send the menu key character to the PDP-11.

Menu Mode can be entered from either the USB port or the AUX port. The menu UI only displays on the port from which it was invoked.

### Transparent Mode

The Console Adapter provides a mode where all characters, including the menu character (`CTRL+^`), are
relayed to the PDP-11 without modification. Transparent mode is useful when transmitting binary data
to the PDP-11 that might contain instances of the menu character. While in Transparent Mode, it is not
possible to access the Console Adapter's menus.

To enter Transparent Mode, choose the **Enter transparent mode** option from the Main Menu (key sequence: `CTRL+^ T`).

To exit Transparent Mode, power-cycle the PDP-11, or reboot the Console Adapter.

## Virtual Paper Tape Reader

The Console Adapter can emulate a low-speed paper tape reader attached to the PDP-11/05 console. Paper tape image files can be "mounted" on the virtual paper tape reader such that they are available to be read by the PDP-11. Each time the PDP-11 signals to advance the paper tape (via the READER RUN signal) the Console Adapter sends a single byte from the paper tape file to the SCL port. As the paper tape is read, an animated progress bar is displayed showing the logical position of the tape in the reader. When the entirety of the image has been read, the virtual paper tape is automatically unmounted.

The virtual paper tape reader can mount image files that have been stored in the adapter's flash File Library. It is also possible to mount image files that have been uploaded using the XMODEM protocol and stored in RAM.

Note that the mount status of the virtual paper tape reader, and the logical position of the paper tape image, are *not* preserved across reboots of the Console Adapter.

### Mounting a Paper Tape Image

To mount a paper tape image, choose the **Mount paper tape** option from the Main Menu (key sequence: `CTRL+^ m`). This will show the Mount Paper Tape menu:

```
*** MOUNT PAPER TAPE:
  0) PDP-11 BASIC                3) XXDP D1AA ADDRESS TEST UP
  1) CONSOLE ECHO TEST           4) XXDP DZQKC INSTRUCT EXERCISER
  2) SIMPLE MEMORY TEST          5) TU58 BOOTSTRAP
  -----
  A) Absolute Loader             P) Previously uploaded file
  X) Upload file via XMODEM      ESC) Return to terminal mode

>>> 
```

The first half of the menu shows the files stored in the device's File Library. To choose these, press the associated option key.

In the second half of the menu, the **Absolute Loader** option (key sequence: `CTRL+^ m A`) can be used to mount a copy of the Absolute Loader paper tape image.

Select the **Upload file via XMODEM** option (key sequence: `CTRL+^ m X`) to mount a tape image uploaded from a terminal program using the XMODEM protocol.

To mount a file that had been uploaded previously via XMODEM, select the **Previously uploaded file** option (key sequence: `CTRL+^ m P`). Note that this option will not appear if no file has been uploaded.

When a paper tape image is mounted, any previously mounted tape image is unmounted first.

Once a selection is made, the Console Adapter returns to Terminal Mode.

### Unmounting a Paper Tape Image

The currently mounted paper tape image can be unmounted using the **Unmount paper tape** option from the Main Menu (key sequence: `CTRL+^ u`).

If there is no paper tape mounted, choosing this option has no effect.

### Viewing Status of the Paper Tape Reader

To view the status of the paper tape reader choose the **Adapter status** option from the Main Menu (key sequence: `CTRL+^ s`). The status shows the name of the paper tape image that is currently mounted (if any) and the current position of the tape in the virtual paper tape reader.

## M9312/M9301 Console Loader

If the PDP-11 contains a [M9312](https://gunkies.org/wiki/M9312_ROM) or [M9301](https://gunkies.org/wiki/M9301_ROM) Bootstrap Terminator module, the Console Adapter can load programs or other data directly into the memory of the PDP-11/05 using the UI provided by the module's console ROM.

The Console Loader feature works by issuing a series of Load Address (L) and Deposit (D) commands to the console and monitoring the responses. The Console Adapter automatically detects data files in Absolute Loader (LDA) format and arranges to load their contents at the correct memory offsets.

The Console Adapter includes special support for loading the PDP-11 Bootstrap Loader (as described below). A similar feature is available for loading the Absolute Loader, which allows for bypassing the Bootstrap Loader step completely (also described below).

### Loading Absolute Loader (LDA) Files

To load an Absolute Loader (LDA) file, select the **Load file using M93xx console** option from the Main Menu (key sequence: `CTRL+^ l`). This will show the Load File menu:

```
*** LOAD FILE:
  0) PDP-11 BASIC                3) XXDP D1AA ADDRESS TEST UP
  1) CONSOLE ECHO TEST           4) XXDP DZQKC INSTRUCT EXERCISER
  2) SIMPLE MEMORY TEST          5) TU58 BOOTSTRAP
  -----
  A) Absolute Loader             P) Previously uploaded file
  B) Bootstrap Loader            ESC) Return to terminal mode
  X) Upload file via XMODEM

>>> 
```

Once a file has been selected, the Console Adapter will inspect the file to determine if it is in Absolute Loader (LDA) format. If it is, the adapter will use the addressing information encoded in the file to place the file's contents at the correct locations in memory.

If the file contains a program start address, the start address will be loaded into the console using the 'L' command as the final step of the loading process. This makes it convenient to start the program by entering an 'S' command.

Once the load operation has completed, the Console Adapter returns to Terminal Mode.

### Loading Simple Data Files

Loading a simple (non-LDA) data file is similar to loading an LDA file. Select the **Load file using M93xx console** option from the Main Menu (key sequence: `CTRL+^ l`), which will show the Load File menu:

```
*** LOAD FILE:
  0) PDP-11 BASIC                3) XXDP D1AA ADDRESS TEST UP
  1) CONSOLE ECHO TEST           4) XXDP DZQKC INSTRUCT EXERCISER
  2) SIMPLE MEMORY TEST          5) TU58 BOOTSTRAP
  -----
  A) Absolute Loader             P) Previously uploaded file
  B) Bootstrap Loader            ESC) Return to terminal mode
  X) Upload file via XMODEM

>>> 
```

If the file selected is a simple data file, the Console Adapter will prompt for a load address:

```
>>> INPUT LOAD ADDRESS (in octal) : 0
```

Pressing ENTER without entering an address will select the default load address, as shown in the input field.

Once an address has been entered, the Console Adapter will load the contents of the data file into memory starting at the specified address. When the load operation completes, the Console Adapter returns to Terminal Mode.

### Loading the Bootstrap Loader

The Console Adapter provides a special option for loading the [PDP-11 Bootstrap Loader](https://gunkies.org/wiki/PDP-11_Bootstrap_Loader) via the M9312/M9301 console ROM. This feature can be used to avoid the need to toggle the loader into the system using the console switches.

To load the Bootstrap Loader, select the **Load file using M93xx console** option from the Main Menu and choose the **Bootstrap Loader** option (key sequence: `CTRL+^ l B`).

The Console Adapter will then prompt for the system memory size:

```
>>> INPUT SYSTEM MEMORY SIZE (in KW): 28
```

Enter the system memory size in KW, using decimal notation. Pressing ENTER without entering a size will select the default memory size, as shown in the input field.

Per the DEC instructions for using the Bootstrap Loader, the selected memory size determines the address at which the loader is loaded, as shown in the following table:

| System Memory Size | Bootstrap Location |
|:-----:|:-----:|
| 4KW  | 017744 |
| 8KW  | 037744 |
| 12KW | 057744 |
| 16KW | 077744 |
| 20KW | 117744 |
| 24KW | 137744 |
| 28KW | 157744 |

Once a memory size has been entered, the Console Adapter proceeds to load the Bootstrap Loader at the given memory location. As it does so, it automatically adjusts the contents of the loader for operation at the target memory location, as described in the associated DEC documentation.

As the final step of loading, the Console Adapter loads the start address of the Bootstrap Loader into the console using the 'L' command, allowing the user to start the loader using the 'S' command.

Note that, by design, the Bootstrap Loader expects to read the Absolute Loader from the system's tape reader. Therefore it is best to mount the Absolute Loader tape image prior to starting the Bootstrap Loader.

By default, the Bootstrap Loader is configured to read data from a low-speed paper tape reader attached to the PDP-11/05's SCL port (which in this context is the Console Adapter itself). This can be changed by modifying the paper tape reader CSR address stored in the last word of the Bootstrap Loader. See [here](https://gunkies.org/wiki/PDP-11_Bootstrap_Loader) or the associated DEC documentation for how to do this.

Note that, while traditionally the Bootstrap Loader is used as the first step in loading programs via paper tape, with the Console Adapter this step can be skipped by loading the Absolute Loader directly, as described in the following section.

### Loading the Absolute Loader

The Console Adapter provides the ability to load the PDP-11 Absolute Loader directly into memory using the M9312/M9301 console. This makes it possible to bypass the step of entering and running the Bootstrap Loader. Technically, when operated this way, the Console Adapter loads both the Absolute Loader and the Bootstrap Loader in one step. This ensures that system memory is arranged the same way as if the Bootstrap Loader had been loaded as a separate step.

To load the Absolute Loader directly, select the **Absolute Loader** option from the Load File menu (key sequence: `CTRL+^ l A`). Once selected, the Console Adapter will prompt for the system memory size:

```
>>> INPUT SYSTEM MEMORY SIZE (in KW): 28
```

Enter the system memory size in KW, using decimal notation. Pressing ENTER without entering a size will select the default memory size, as shown in the input field.

As with loading the Bootstrap Loader, the selected memory size determines the address at which the Absolute Loader is loaded (see the section on Loading the Bootstrap Loader for details).

As the final step of loading, the Console Adapter loads the start address of the Absolute Loader into the console using the 'L' command. This allows the user to start the loader using the 'S' command.

When the Absolute Loader starts, it expects to read a paper tape in LDA format from the system's tape reader. Therefore it is best to mount the desired tape image prior to starting the loader.

## Adapter Settings

The Console Adapter provides a number of options for controlling its behavior. To view or change the adapter's settings, select **Adapter settings** from the Main Menu (key sequence: `CTRL+^ S`). This will display the Settings Menu:

```
*** SETTINGS MENU:
  s) Default SCL config....9600-8-N-2  a) Default Aux config....9600-8-N-1
  S) SCL follows USB...............on  A) Aux follows USB..............off
  p) Show PTR progress.............on  u) Uppercase mode...............off
  -----
  ESC) Return to terminal mode

>>> 
```

Changes made to settings via the settings menu are persisted in the adapter's flash memory and therefore are retained across power cycles.

### Changing the SCL Port Configuration

The Console Adapter includes a baud clock generator which allows it to dynamically adjust the speed of the PDP-11/05's SCL port. While in Terminal Mode, the adapter listens for requests from the attached USB host to change the serial configuration. These requests are known as *CDC Line Coding Requests* in USB parlance. Most terminal emulator programs, such as PuTTY or minicom, provide a way to send serial configuration requests using a key sequence or menu option.

When the adapter receives a serial configuration change request, it automatically adjusts the SCL port to match the requested configuration, provided the requested configuration is supported. The Console Adapter supports all standard serial bit rates in the range 110 to 38400 (the range supported by the PDP-11/05 hardware). Supported serial formats for the SCL port are 8-N-2, 7-E-2 and 7-O-2. For compatibility with modern terminal emulators, the Console Adapter will also accept serial formats 8-N-1, 7-E-1 and 7-O-1, and will translate these to their 2 stop bit equivalents internally.

Note that most terminal emulators issue a request to change the serial configuration as soon as they connect to a USB COM device. The effect of this is that the SCL port's configuration will snap to whatever configuration is the default for the terminal emulator at the time it is started. For many terminal programs, this is 9600 8-N-1.

By default, the Console Adapter is pre-configured to listen and react to serial change requests from the USB host. This feature can be disabled by changing the **SCL follows USB** setting to **off** in the **Settings Menu** (key sequence: `CTRL+^ S S`). When this setting is off, the adapter will always use the default SCL port configuration set in the Settings Menu (see below).

### Default SCL Port Configuration

If there is no USB connection when the Console Adapter boots, the adapter will configure the SCL port using default settings stored in its persistent memory. This allows the selection of a particular serial configuration without needing to attach a USB host (e.g., when using the adapter with an auxiliary terminal only).

The default SCL configuration is preset to 9600-8-N-2, which is a reasonable configuration for most PDP-11 software.

The default configuration can be changed by selecting the **Default SCL config** option in the **Settings Menu** (key sequence: `CTRL+^ S s`). This will display the Port Configuration Menu:

```
*** CHANGE SCL PORT CONFIG:
  0) 110    3) 1200   6) 9600
  1) 300    4) 2400   7) 19200
  2) 600    5) 4800   8) 38400
  -----
  a) 8-N-2  b) 7-E-2  c) 7-O-2
  -----
  ENTER) Accept    ESC) Abort

>>> 9600-8-N-2
```

The current serial configuration is shown after the prompt. Selecting the various menu options will adjust the bit rate and/or serial format accordingly. Pressing *ENTER* will accept the new configuration, while pressing *ESC* will discard it.

### Changing the AUX Port Configuration

When the Console Adapter boots, it configures the AUX port using a set of default settings stored in persistent memory. These settings can be changed by choosing the **Default AUX config** option via the adapter's Settings Menu (key sequence: `CTRL+^ S a`).

The AUX port configuration is preset to 9600-8-N-1.

Similar to the SCL port, the AUX port can be configured to automatically adjust its serial configuration to match the configuration requested by an attached USB host. This feature is disabled by default, as most serial terminals cannot dynamically adapt their serial configuration on the fly. To enable automatic adjustment of the AUX port configuration, change the **AUX follows USB** setting to **on** in the Settings Menu (key sequence: `CTRL+^ S A`).

### Controlling the Paper Tape Progress Bar

Whenever the PDP-11 requests a character from the virtual paper tape reader, the Console Adapter shows an animated progress bar depicting the logical position of the tape. This animation can be controlled by selecting the **Show PTR progress** option in the Settings Menu (key sequence: `CTRL+^ S p`). Three modes are available:

```
*** SHOW PAPER TAPE READER PROGRESS BAR:
  0) On
  1) USB only
  2) Off

>>> 
```

**On** enables displaying the progress bar in all contexts, while **Off** disables it entirely.

**USB only** causes the progress bar to be displayed only when the user is interacting with the Console Adapter over USB (i.e. when not interacting via an auxiliary terminal). This mode can be useful when the AUX port is configured to use a slow bit rate that interferes with the smooth animation of the bar.

### Enabling/Disabling Uppercase Mode

The Console Adapter can be placed in a mode where all characters forwarded to the SCL port in Terminal Mode are converted to uppercase first. This mode is useful when working with PDP-11 software, such as PDP-11 Paper Tape BASIC, which requires the user to enter uppercase characters only. It is more convenient than using the keyboard's caps lock key in that only characters sent to the PDP-11 are converted, and the keyboard remains in non-caps lock mode while interacting with the Console Adapter's menus or other programs on the host computer.

Uppercase Mode can be toggled on or off by selecting the **Uppercase mode** option in the Settings Menu (key sequence: `CTRL+^ S u`).

Uppercase Mode is suspended while the Console Adapter is in **[Transparent Mode](#transparent-mode)**.

## Adapter Status

The current status of the Console Adapter can be viewed by selecting the **Adapter status** option from the Main Menu (key sequence: `CTRL+^ s`). The adapter status feature displays the current state of the SCL and AUX ports, as well as the virtual paper tape reader.

```
*** ADAPTER STATUS:
  SCL Port: 9600-8-N-2 (default), connected
  Aux Port: 9600-8-N-1 (default)
  Paper Tape Reader: PDP-11 BASIC (AJPB-PB)
  Position: 9300/10170 (91%)
```

For both the SCL and AUX ports, the display shows the currently active serial configuration and an indication of how this configuration was arrived at. The word **default** is shown if the port configuration was set based on the defaults given in the Adapter Settings menu. The words **set via USB** are shown if the port configuration was set via a serial configuration change request received over USB.

For the SCL port, the words **connected** or **disconnected** will appear indicating whether the Console Adapter detects an electrical connection with the PDP-11's SCL port.

For the virtual paper tape reader, the adapter will show the name of the currently mounted paper tape image, or **No tape mounted**. If a tape is mounted, the adapter will show the logical position of the tape as a byte offset relative to the total size (e.g. *9300/10170*) as well as a percentage.

## Flash File Library

The Console Adapter provides the ability to store frequently used paper tape images and other data files on the Console Adapter itself, such that they are readily available for use when working with the PDP-11. Files are stored in the Pico's flash memory alongside the adapter's firmware, and thus are preserved across reboots. The files in the file library appear as choices in the Mount Paper Tape and Load File menus.

Each file in the library can be up to 128KiB in size. The library itself can contain a maximum of 36 files totaling up to 1MiB in size.

File names are limited to 32 characters.

### Creating a File Library Image

To update the file library on the Console Adapter, one must first create a **file library image**. A file library image is a [UF2](https://github.com/microsoft/uf2) file that contains the contents of all the files in the library along with associated metadata (file names, sizes and checksums). Being a UF2 file, the library image file can be written directly to the Pico's flash memory using the standard Pico flash procedure (see below).

The `mkfilelib.py` command-line tool can be used to construct a new file library image. The tool takes the name of the image file to be created, followed by a list of files to be included in the image:

```bash
./tools/mkfilelib.py my-file-lib.uf2 paper-tape/DEC-11-AJPB-PB.ptap paper-tape/DEC-11-ASPA-PB.ptap
```

When presented in a menu, files in the file library appear in the order they are listed on the command line, and use the given file name, excluding any path component:

```
*** MOUNT PAPER TAPE:
  0) DEC-11-AJPB-PB.ptap        1) DEC-11-ASPA-PB.ptap
  -----
  A) Absolute Loader            ESC) Return to terminal mode
  X) Upload file via XMODEM

>>> 
```

File names longer than 32 characters are silently truncated when generating a library image.

### Flashing a New File Library

Once a new file library image has been created, the process to flash the library onto the Console Adapter is the same as updating the adapter's firmware:

- Start with the Console Adapter in a powered-off state by powering off the PDP-11 (if attached) and disconnecting the USB connection to the host computer.
- While holding down the BOOTSEL button on the Pico, plug in the USB cable to the host computer.
- When the Pico virtual drive appears on the host computer (look for a drive named "RPI-RP2"), drag or copy the library image file (.uf2 file) onto the drive.
- After a moment, the virtual drive will disappear and the Console Adapter will reboot.
- Once the device finishes rebooting, the new file library is available for use.

## Copyright

Copyright 2025 Jay Logue

All documentation for the PDP-11/05 Console Adapter V2, including images, schematics, PCB designs and this manual, is licensed under a [Creative Commons Attribution 4.0 International License](https://creativecommons.org/licenses/by/4.0/).

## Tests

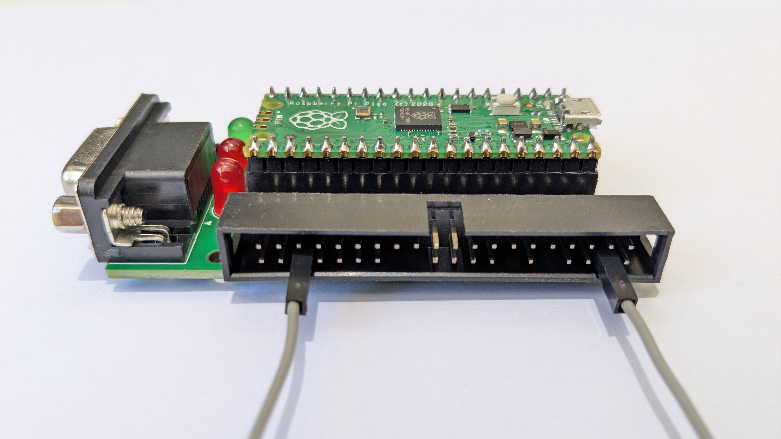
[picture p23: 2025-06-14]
docs/media/pdp1105-console-adapter-loopback-test-2.jpg

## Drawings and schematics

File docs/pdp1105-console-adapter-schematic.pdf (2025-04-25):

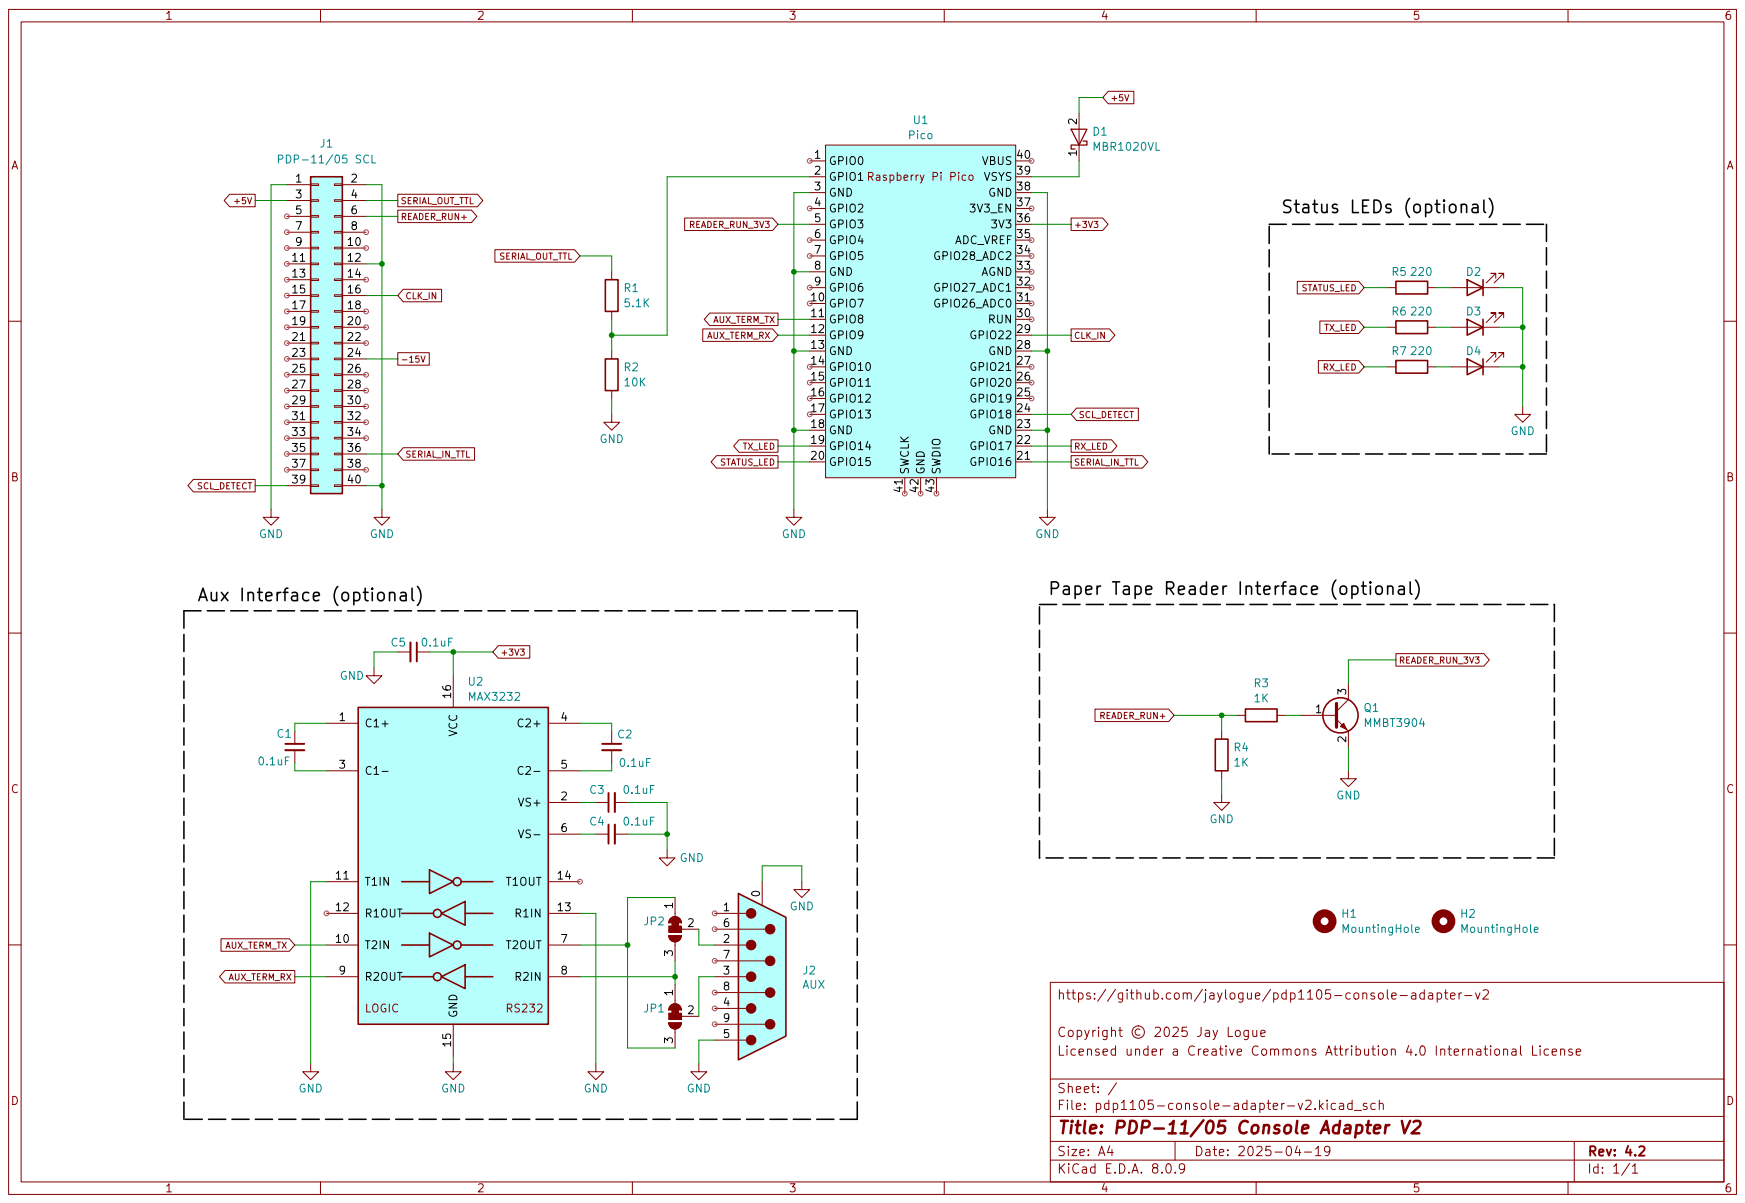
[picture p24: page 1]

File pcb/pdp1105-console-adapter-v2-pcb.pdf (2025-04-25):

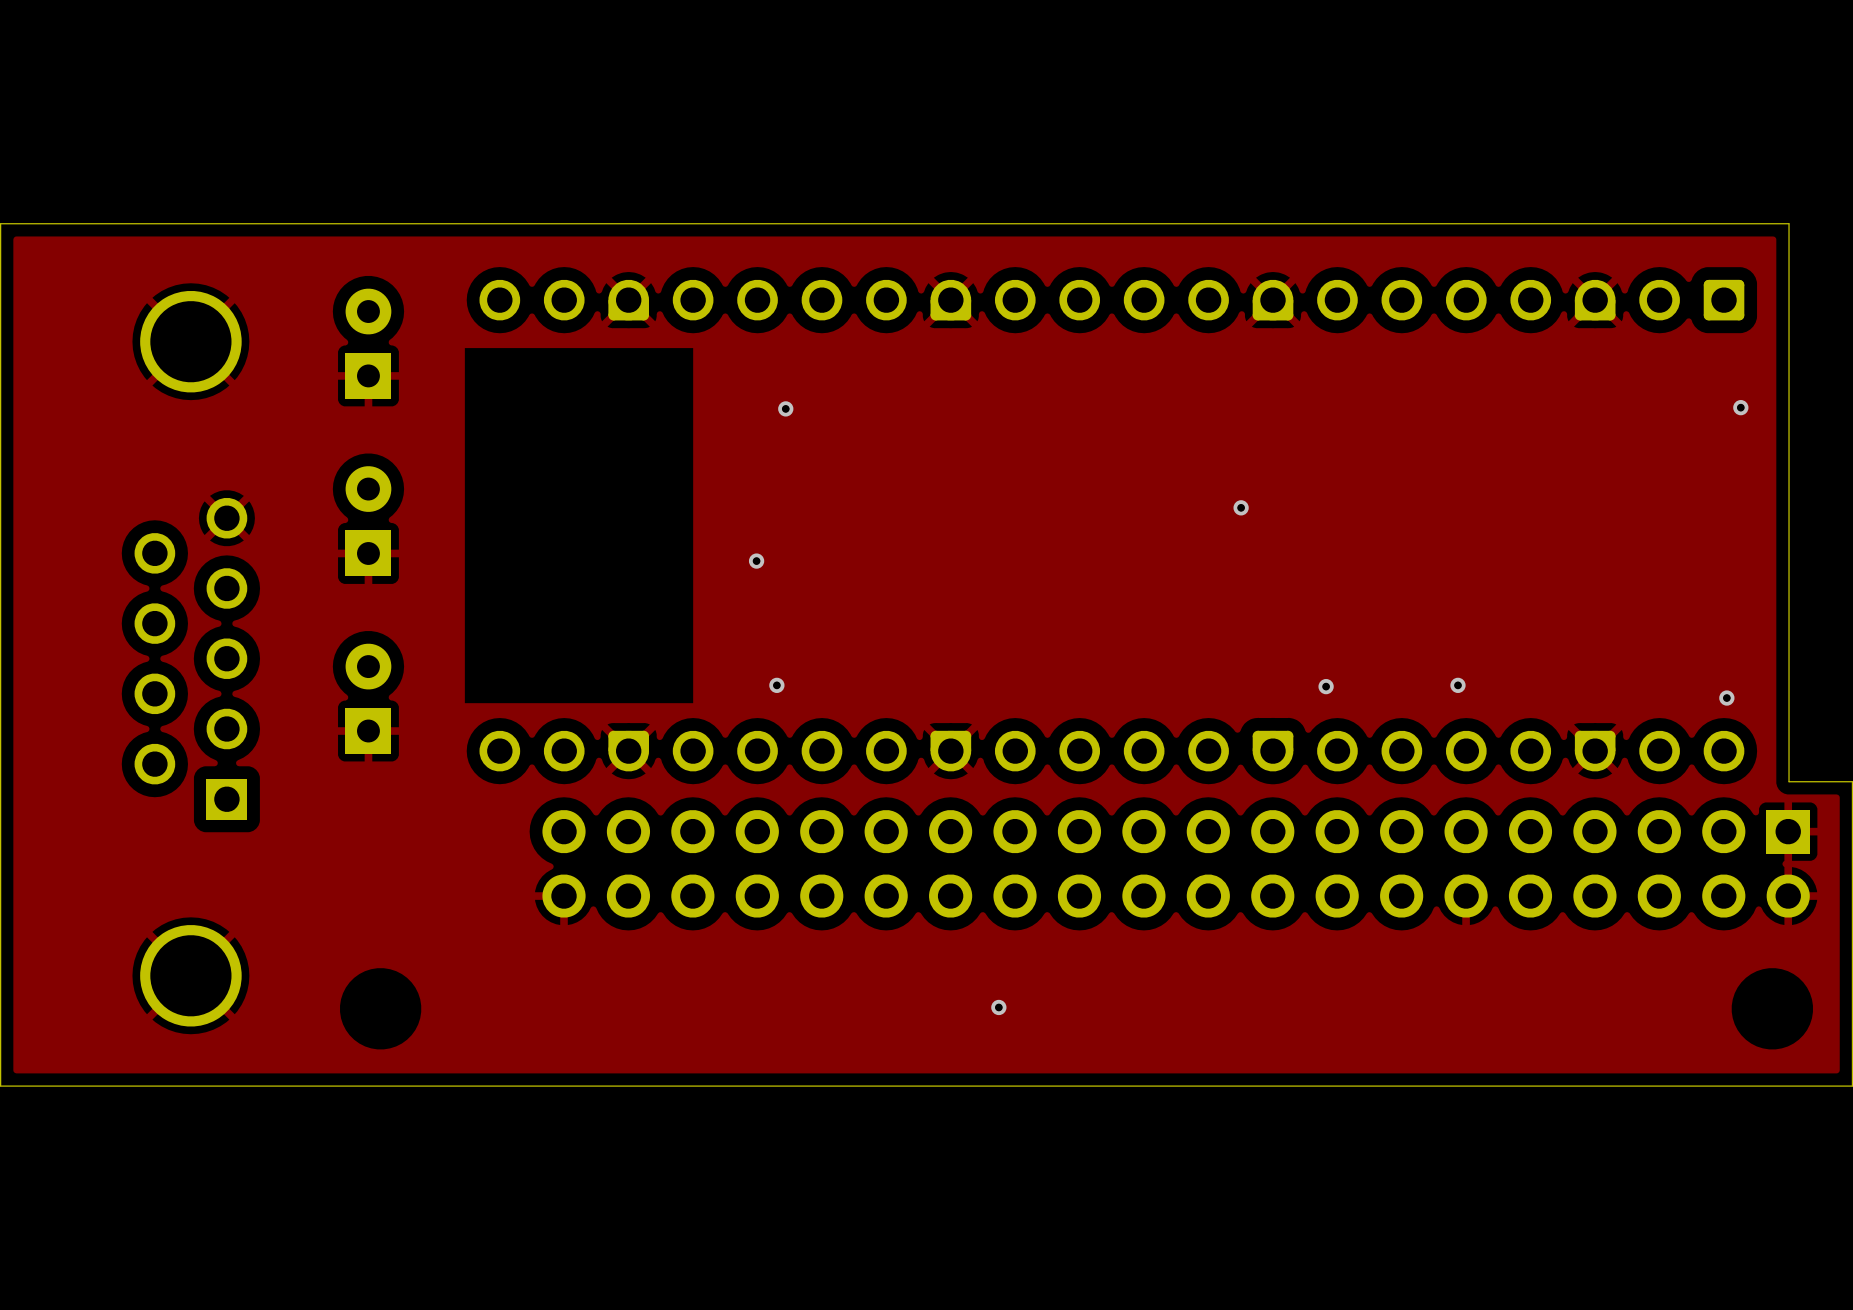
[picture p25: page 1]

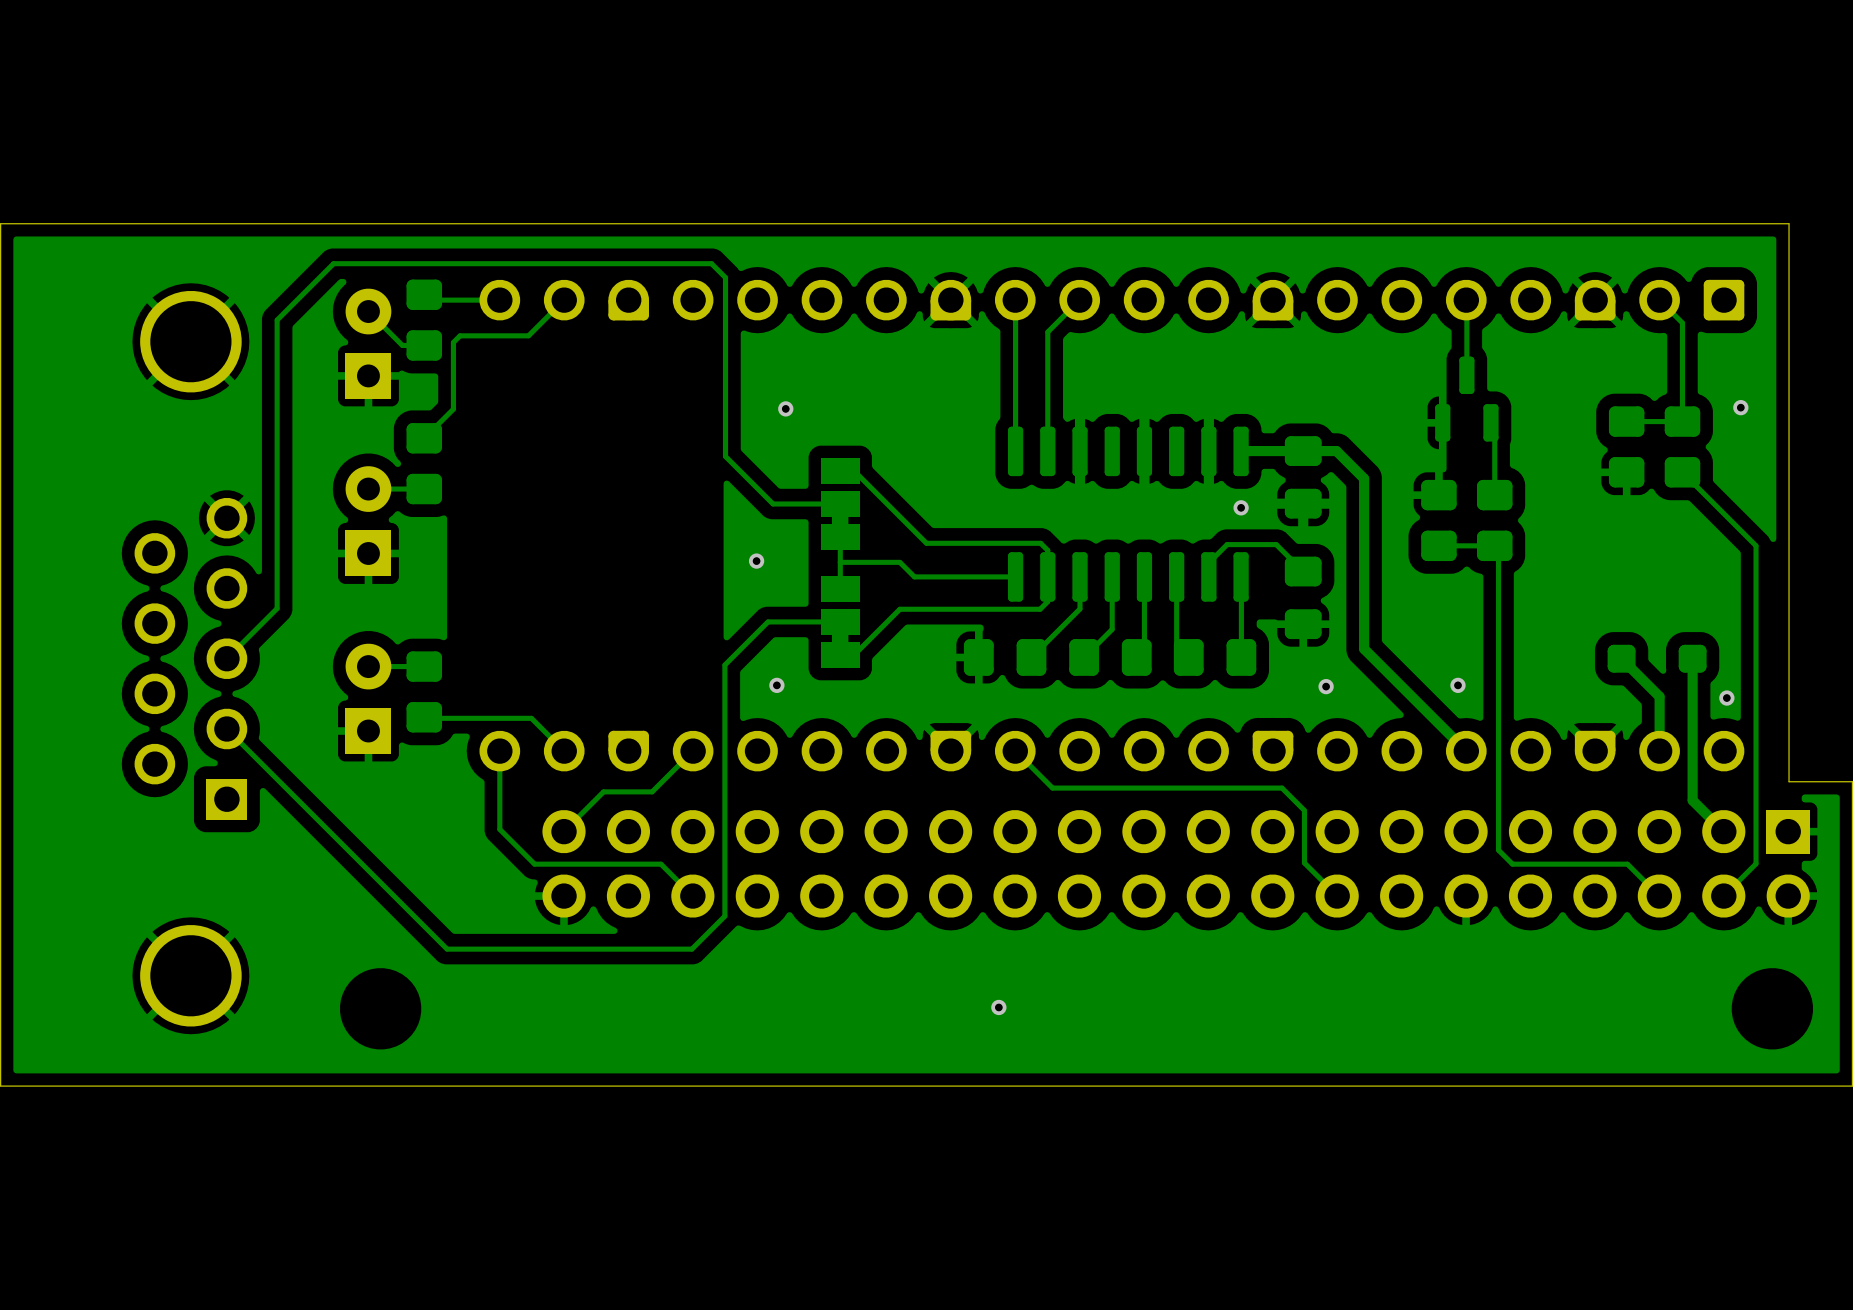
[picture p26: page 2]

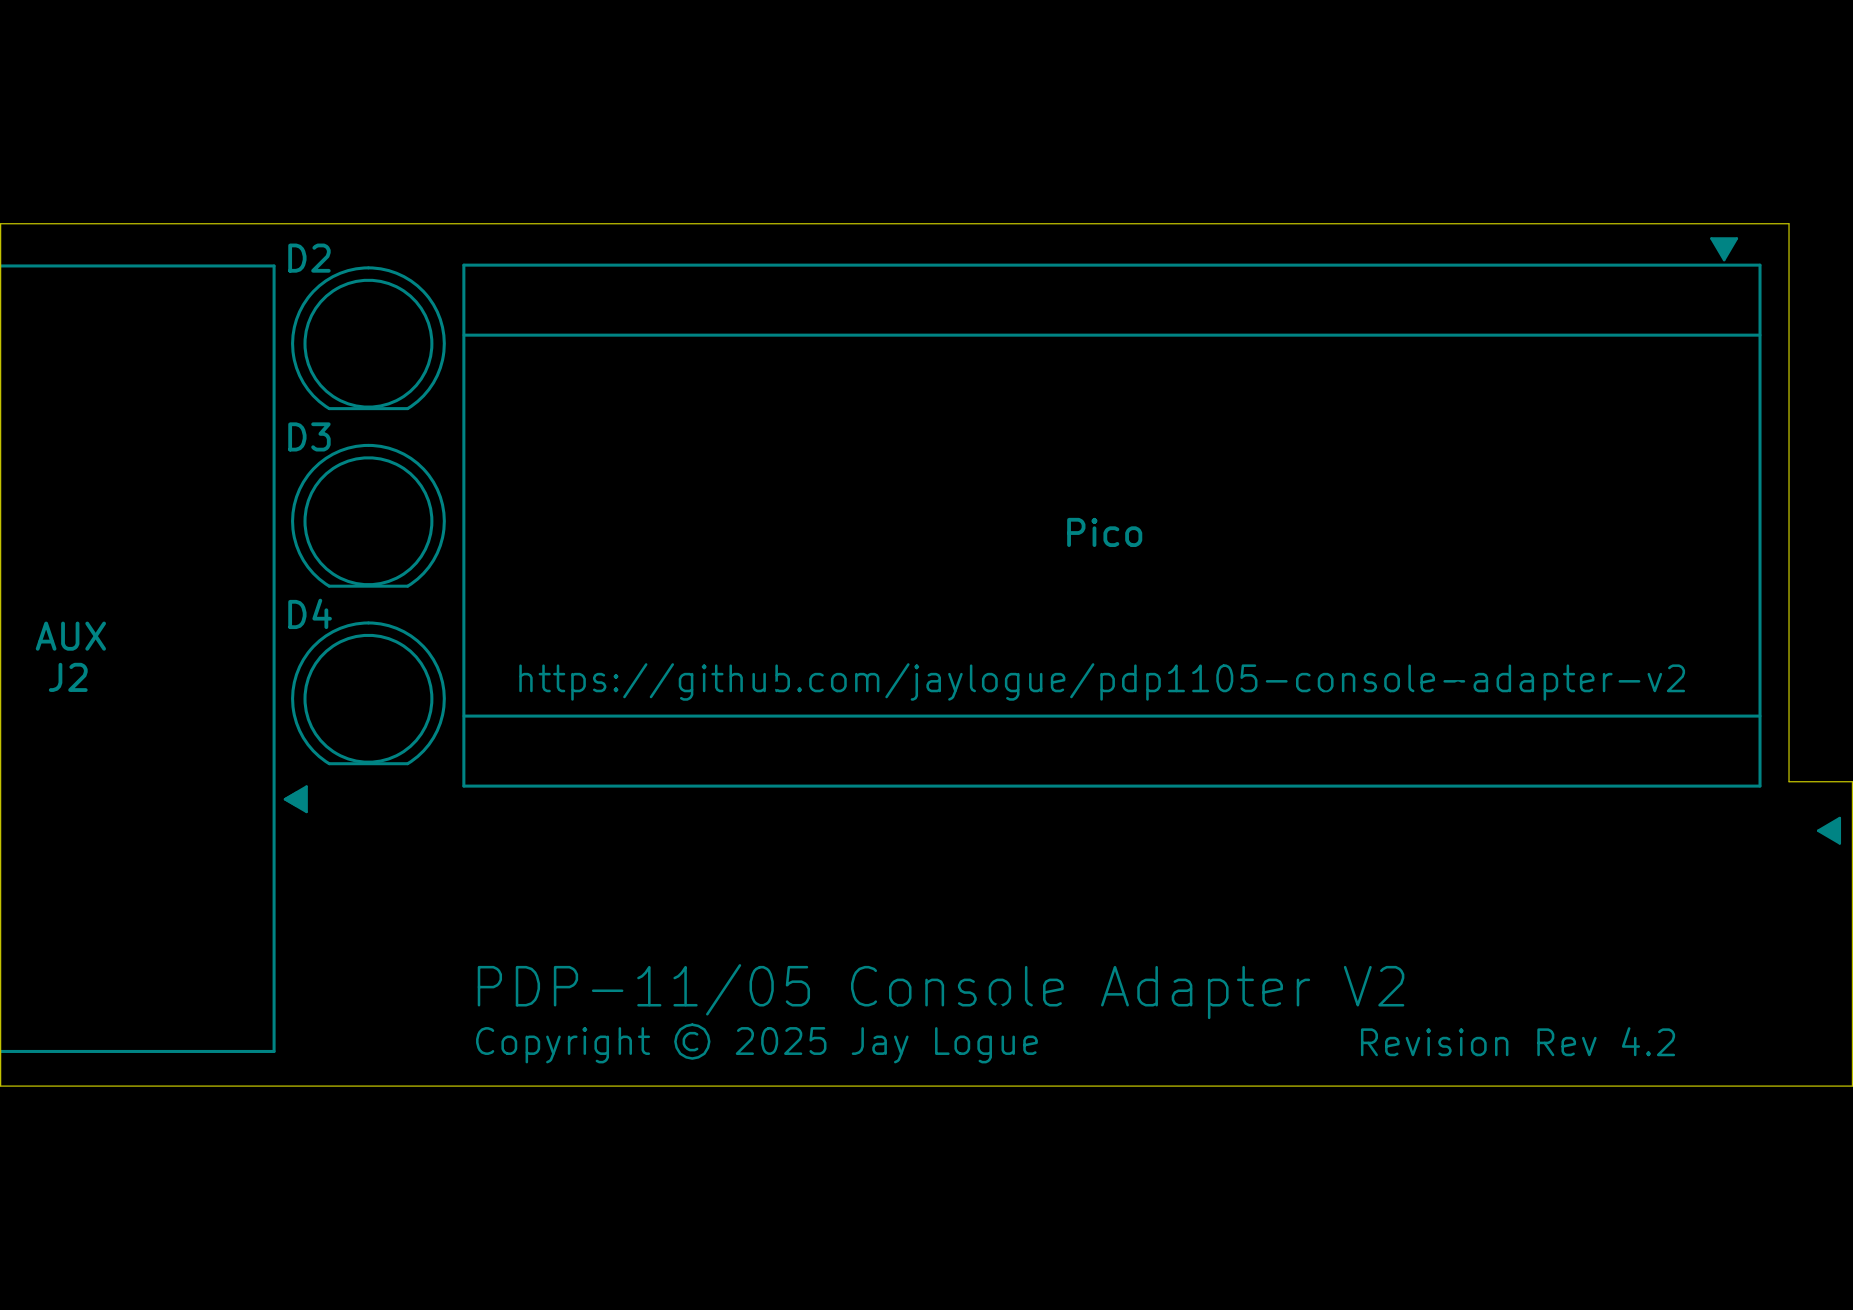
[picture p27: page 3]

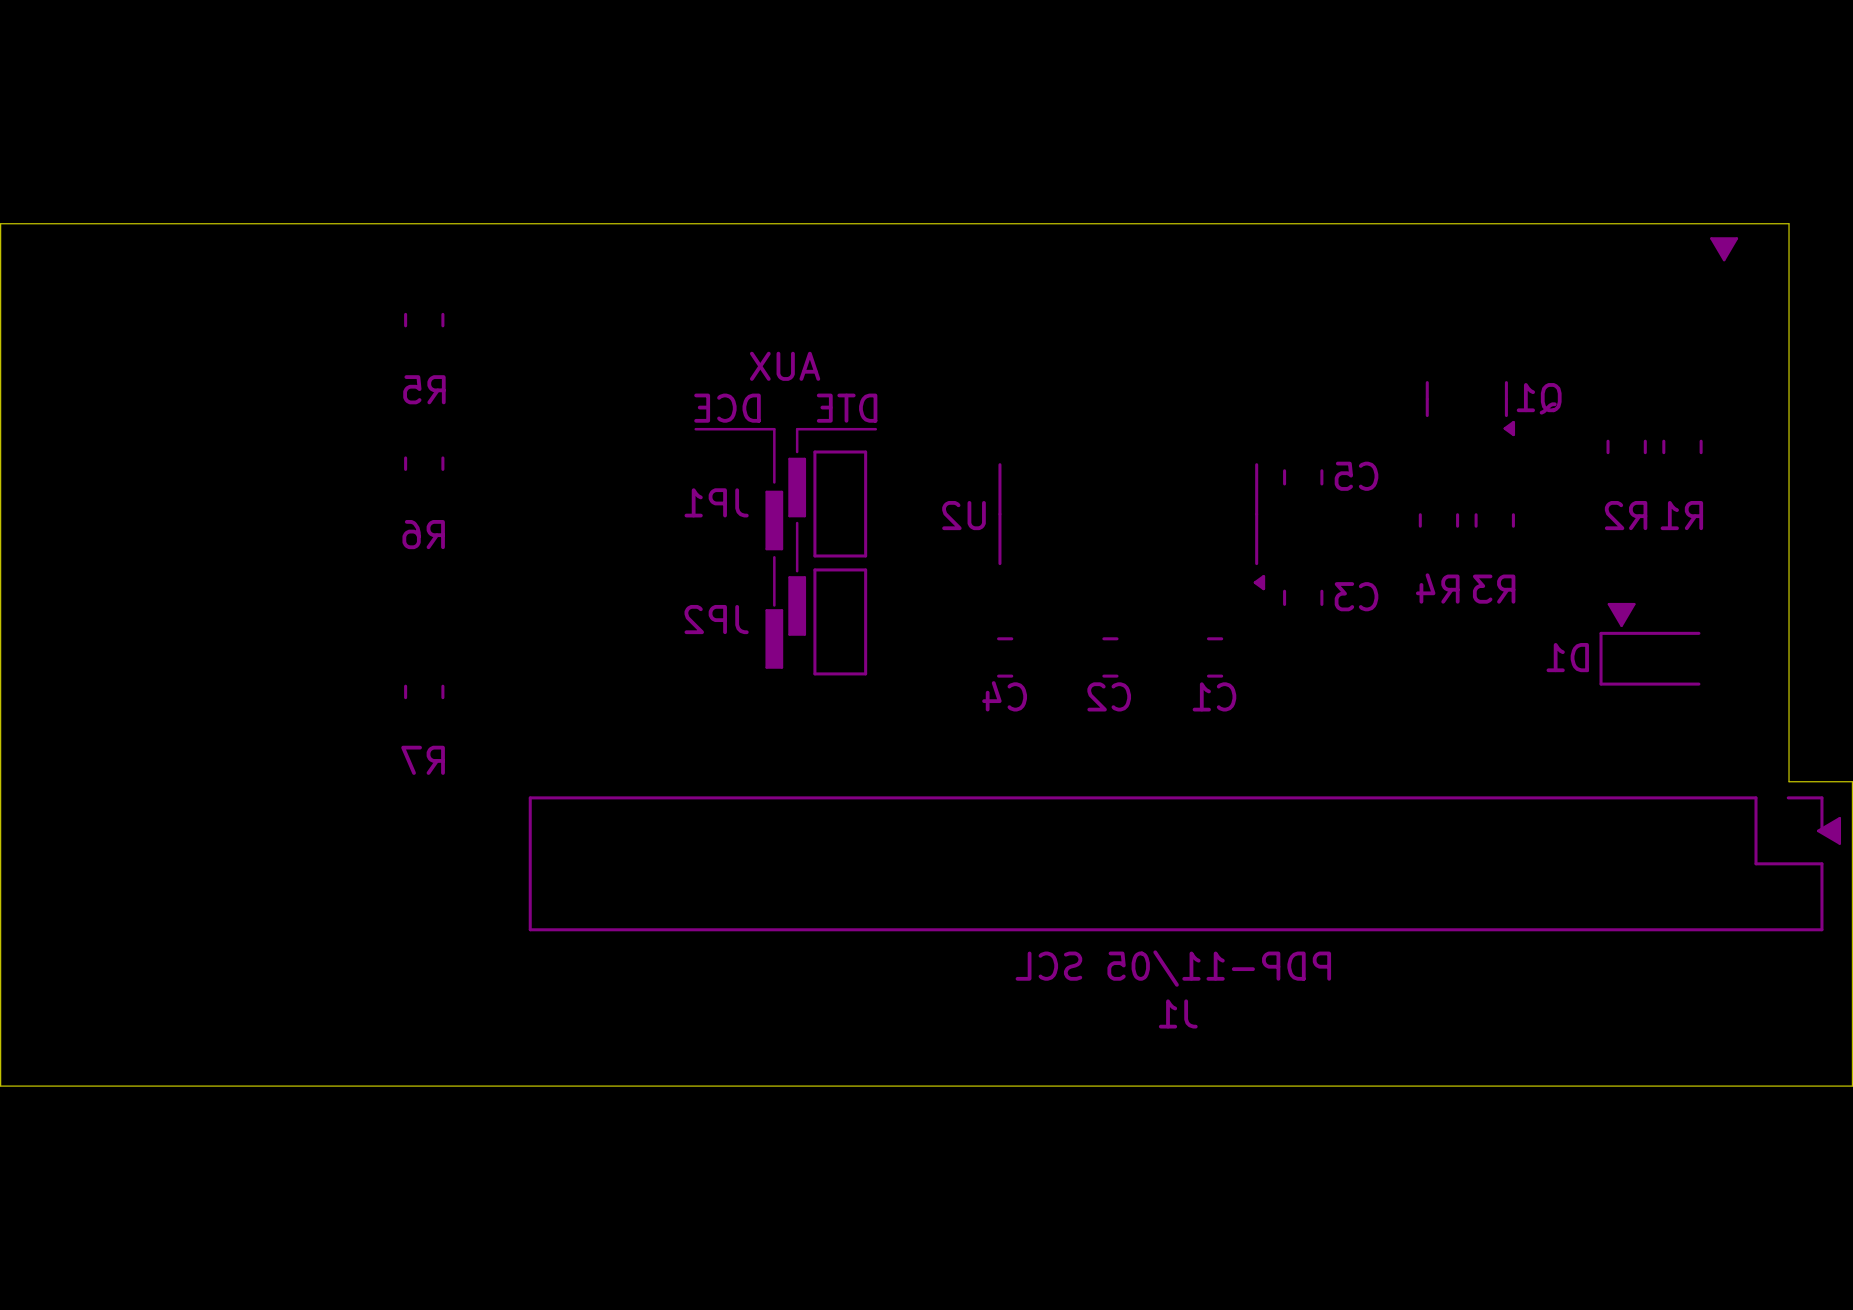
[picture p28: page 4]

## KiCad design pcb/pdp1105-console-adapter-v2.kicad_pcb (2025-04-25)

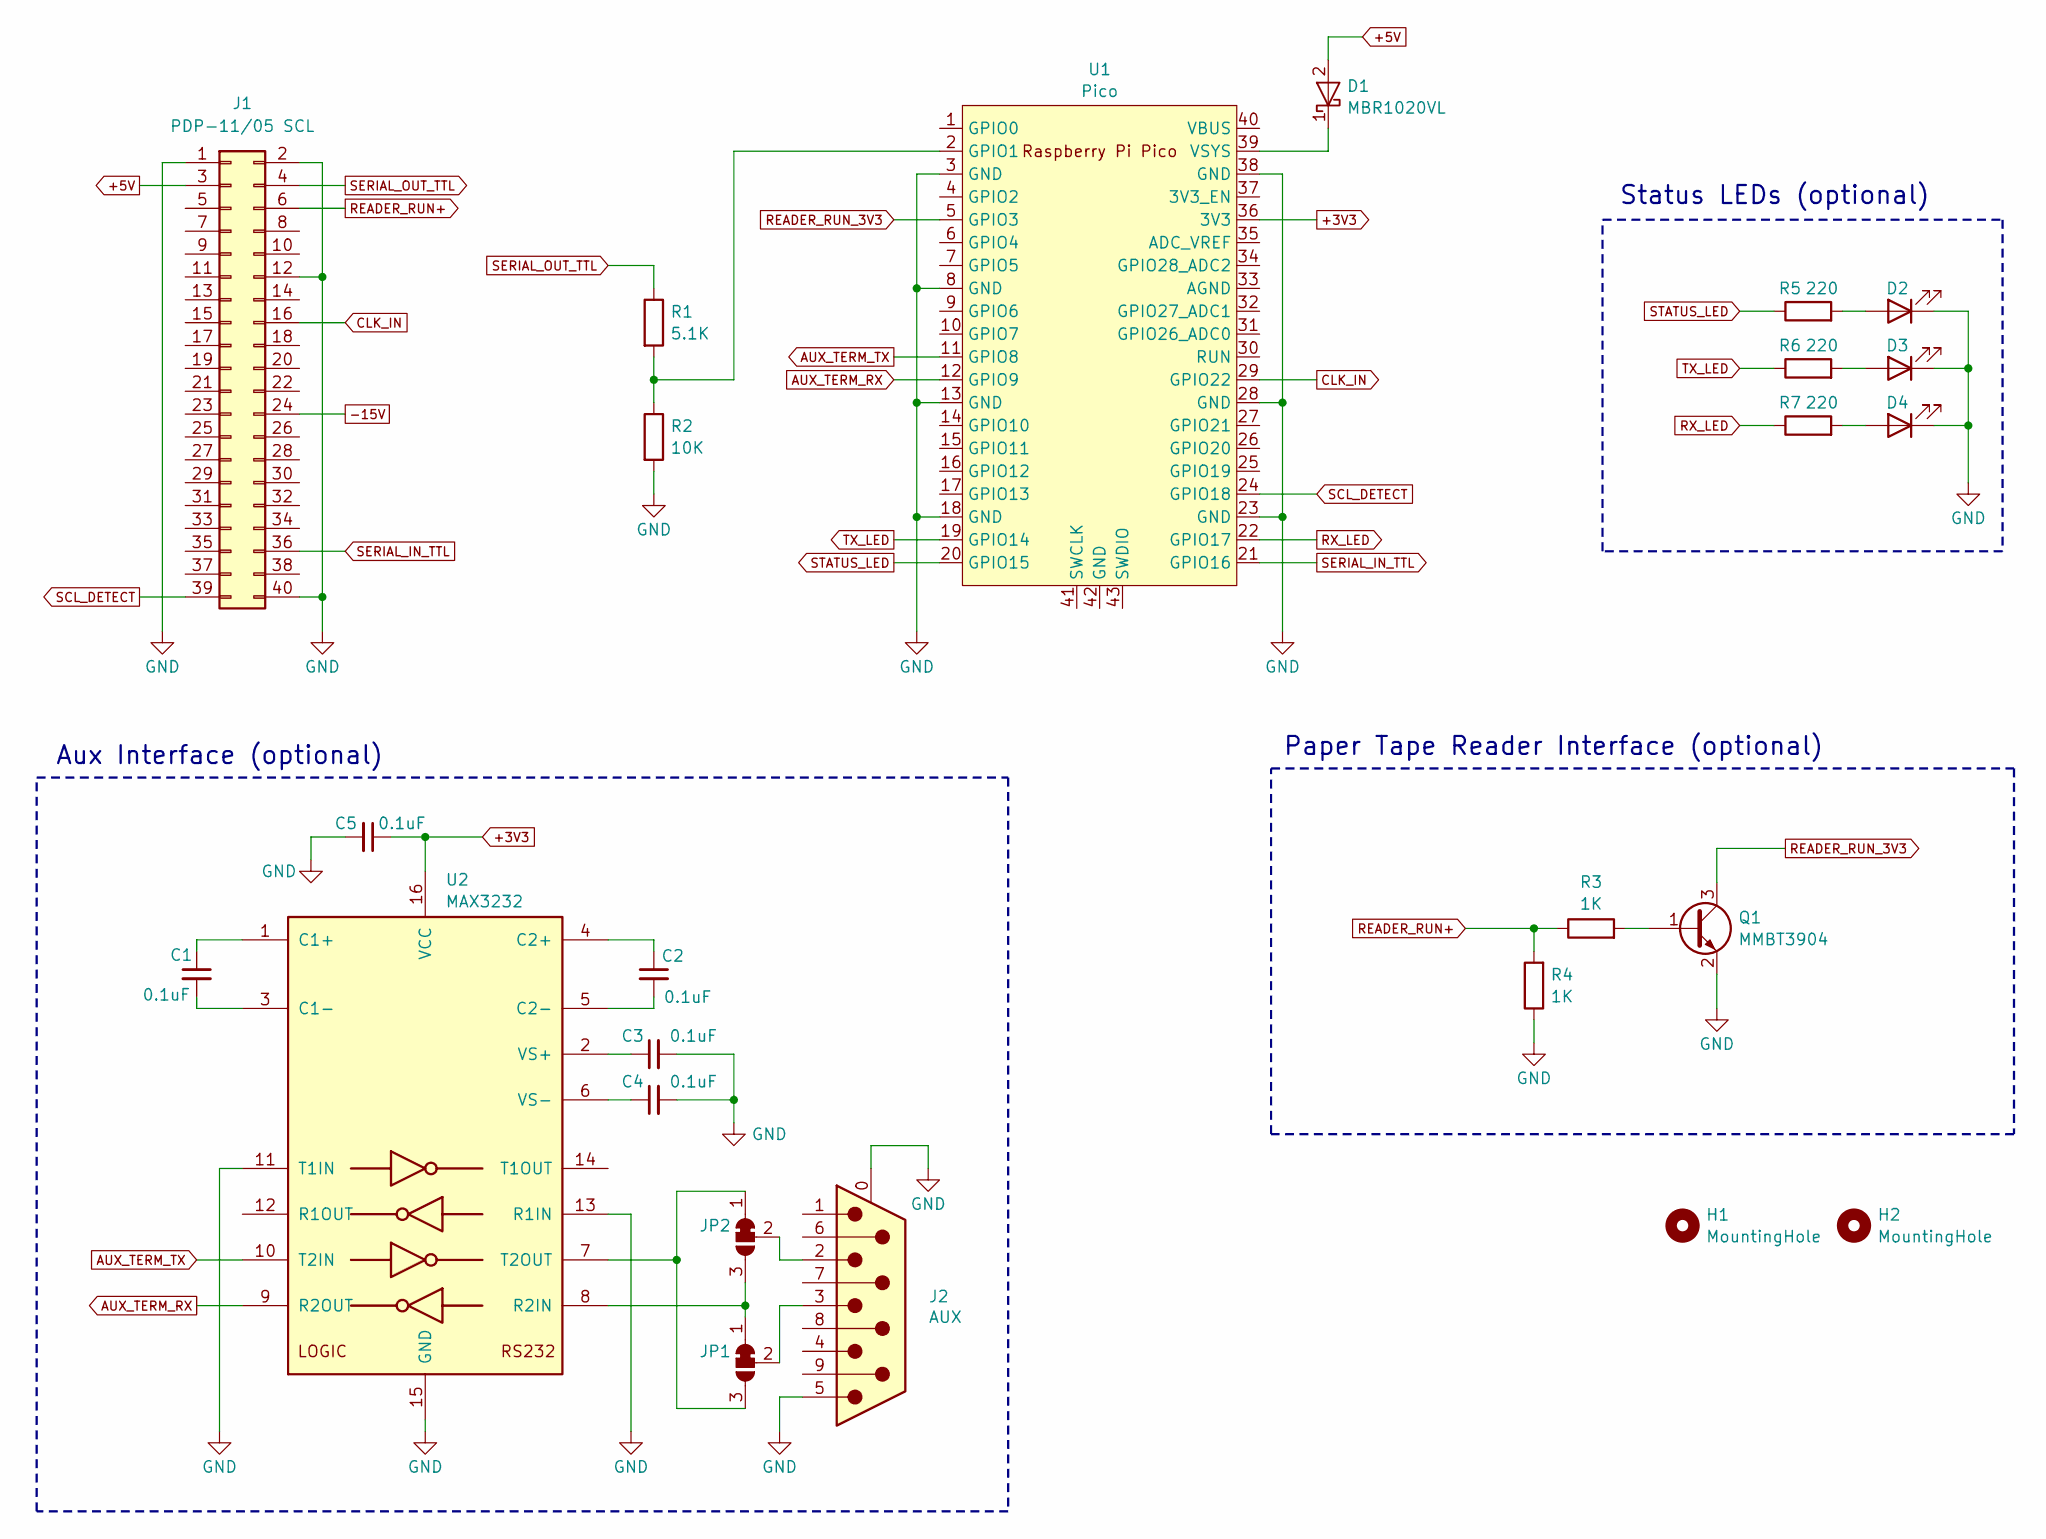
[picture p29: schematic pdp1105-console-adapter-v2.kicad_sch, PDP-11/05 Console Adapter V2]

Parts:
C1, C2, C3, C4, C5: 0.1uF; C_0805_2012Metric_Pad1.18x1.45mm_HandSolder; LCSC C28233
D1: MBR1020VL; D_SOD-123F; LCSC C391533
D2, D3, D4: LED; LED_D5.0mm
H1, H2: MountingHole; MountingHole_2.7mm_M2.5
J1: PDP-11/05 SCL; PinSocket_2x20_P2.54mm_Vertical
J2: AUX; DSUB-9_Female_Horizontal_P2.77x2.84mm_EdgePinOffset7.70mm_H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
JP1, JP2: SolderJumper_3_Bridged12; SolderJumper-3_P1.3mm_Bridged12_Pad1.0x1.5mm
Q1: MMBT3904; SOT-23; LCSC C20526
R1: 5.1K; R_0805_2012Metric_Pad1.20x1.40mm_HandSolder; LCSC C27834
R2: 10K; R_0805_2012Metric_Pad1.20x1.40mm_HandSolder; LCSC C17414
R3, R4: 1K; R_0805_2012Metric_Pad1.20x1.40mm_HandSolder; LCSC C17513
R5, R6, R7: 220; R_0805_2012Metric_Pad1.20x1.40mm_HandSolder; LCSC C17414
U1: Pico; RaspberryPi_Pico_Common_THT
U2: MAX3232; SOIC-16_3.9x9.9mm_P1.27mm; LCSC C9378

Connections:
+3V3: C5.1, U1.36 (3V3), U2.16 (VCC)
+5V: D1.2 (A), J1.3 (+5V)
-15V: J1.24 (-15V)
AUX_TERM_RX: U1.12 (GPIO9), U2.9 (R2OUT)
AUX_TERM_TX: U1.11 (GPIO8), U2.10 (T2IN)
CLK_IN: J1.16 (CLK_IN), U1.29 (GPIO22)
GND: C3.2, C4.2, C5.2, D2.1 (K), D3.1 (K), D4.1 (K), J1.1 (GND), J1.2 (GND), J1.12 (CLK_DISAB), J1.40 (GND), J2.0 (PAD), J2.5, Q1.2 (E), R2.2, R4.1, U1.3 (GND), U1.8 (GND), U1.13 (GND), U1.18 (GND), U1.23 (GND), U1.28 (GND), U1.38 (GND), U2.11 (T1IN), U2.13 (R1IN), U2.15 (GND)
unnamed: D1.1 (K), U1.39 (VSYS)
unnamed: D2.2 (A), R5.2
unnamed: D3.2 (A), R6.2
unnamed: D4.2 (A), R7.2
unnamed: JP1.1 (A), JP2.3 (B), U2.8 (R2IN)
unnamed: JP1.3 (B), JP2.1 (A), U2.7 (T2OUT)
unnamed: J2.3, JP1.2 (C)
unnamed: J2.2, JP2.2 (C)
unnamed: Q1.1 (B), R3.2
unnamed: R1.2, R2.1, U1.2 (GPIO1)
unnamed: C1.1, U2.1 (C1+)
unnamed: C1.2, U2.3 (C1-)
unnamed: C2.1, U2.4 (C2+)
unnamed: C2.2, U2.5 (C2-)
unnamed: C3.1, U2.2 (VS+)
unnamed: C4.1, U2.6 (VS-)
READER_RUN+: J1.6 (+READER_RUN_20MA), R3.1, R4.2
READER_RUN_3V3: Q1.3 (C), U1.5 (GPIO3)
RX_LED: R7.1, U1.22 (GPIO17)
SCL_DETECT: J1.39 (GND), U1.24 (GPIO18)
SERIAL_IN_TTL: J1.36 (SERIAL_IN_TTL), U1.21 (GPIO16)
SERIAL_OUT_TTL: J1.4 (SERIAL_OUT_TTL), R1.1
STATUS_LED: R5.1, U1.20 (GPIO15)
TX_LED: R6.1, U1.19 (GPIO14)

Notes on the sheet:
Aux Interface (optional)
Status LEDs (optional)
Paper Tape Reader Interface (optional)

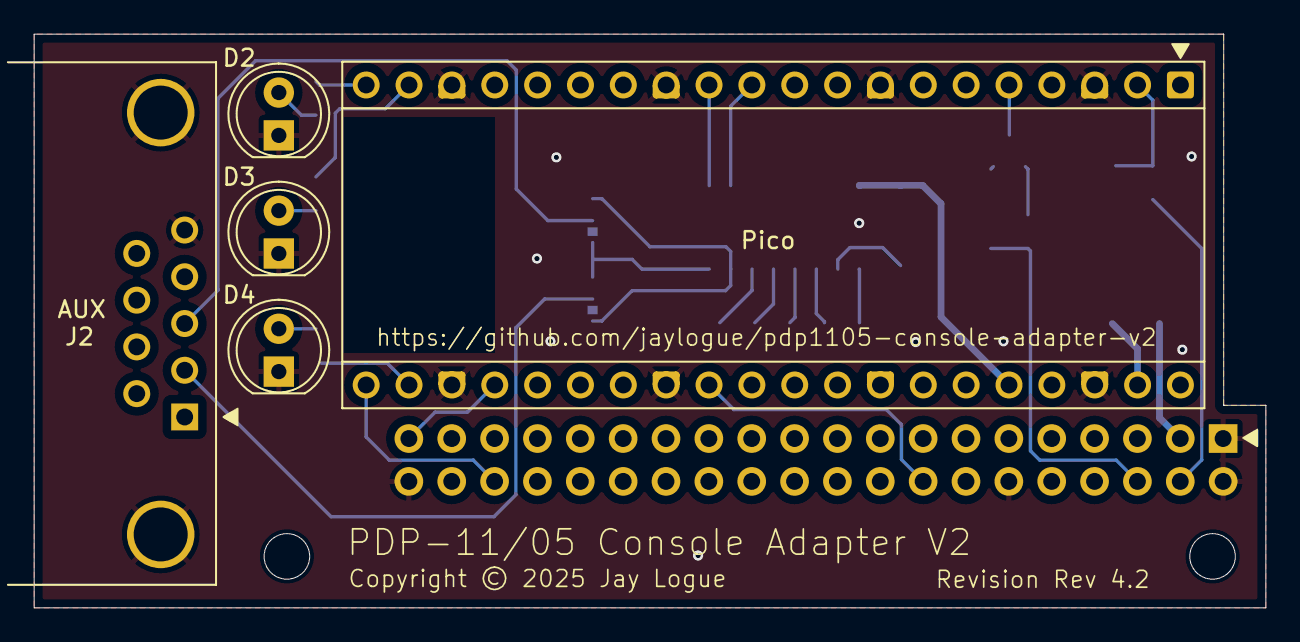
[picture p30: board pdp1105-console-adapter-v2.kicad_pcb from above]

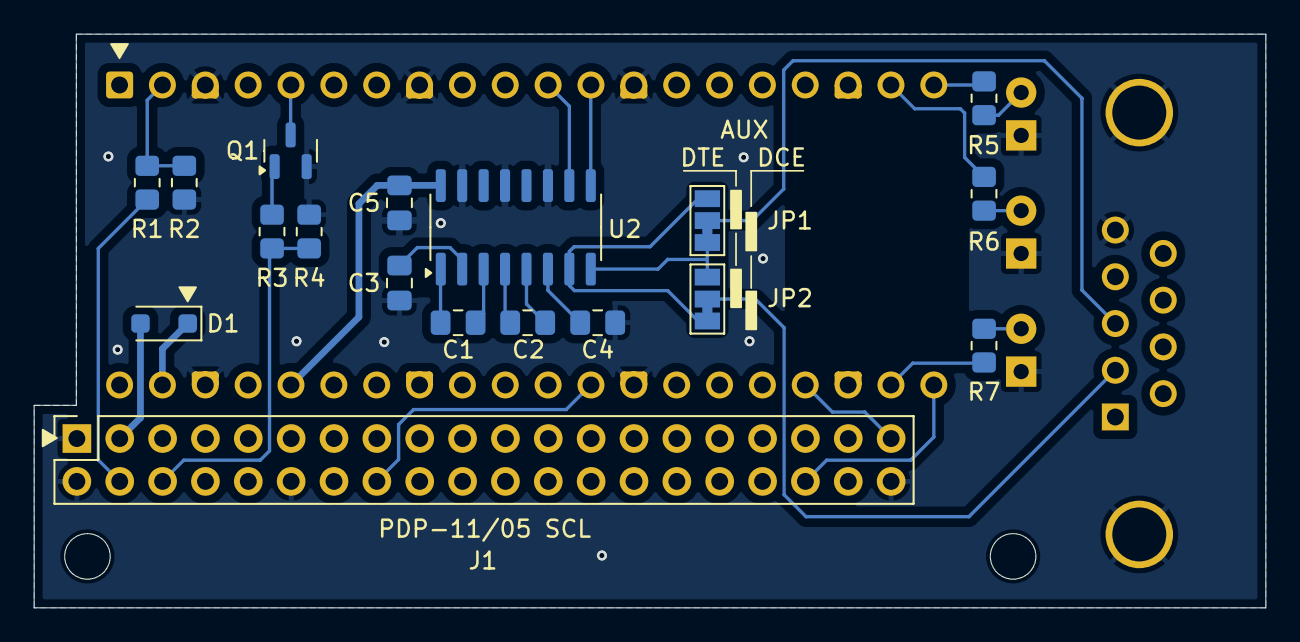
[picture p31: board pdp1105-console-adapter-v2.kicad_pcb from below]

Board: 2 copper layers, 73.0 x 34.0 mm, 25 parts (18 on the bottom side), 30 nets.

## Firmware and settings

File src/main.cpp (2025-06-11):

/*
 * Copyright 2024-2025 Jay Logue
 * 
 * Licensed under the Apache License, Version 2.0 (the "License");
 * you may not use this file except in compliance with the License.
 * You may obtain a copy of the License at
 * 
 *     http://www.apache.org/licenses/LICENSE-2.0
 * 
 * Unless required by applicable law or agreed to in writing, software
 * distributed under the License is distributed on an "AS IS" BASIS,
 * WITHOUT WARRANTIES OR CONDITIONS OF ANY KIND, either express or implied.
 * See the License for the specific language governing permissions and
 * limitations under the License.
 */

/*
 * A Raspberry Pi Pico based USB-to-serial adapter for interfacing with
 * the console of a PDP-11/05. 
 */

#include "ConsoleAdapter.h"
#include "Settings.h"
 
int main()
{
    // Initialize access to persisted settings
    Settings::Init();

    // Initialize the host USB interface
    gHostPort.Init();

    // Initialize the SCL port and set the initial serial configuration
    gSCLPort.Init();
    gSCLPort.SetConfig(Settings::SCLConfig);

#if defined(AUX_TERM_UART)
    // Initialize the Aux Terminal port and set the initial serial configuration
    gAuxPort.Init();
    gAuxPort.SetConfig(Settings::AuxConfig);
#endif

    // Initialize access to built-in file library.
    FileLib::Init();

    // Initialize the activity LEDs
    ActivityLED::Init();

    // Enter Terminal mode
    TerminalMode();
}

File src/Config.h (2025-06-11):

/*
 * Copyright 2024-2025 Jay Logue
 * 
 * Licensed under the Apache License, Version 2.0 (the "License");
 * you may not use this file except in compliance with the License.
 * You may obtain a copy of the License at
 * 
 *     http://www.apache.org/licenses/LICENSE-2.0
 * 
 * Unless required by applicable law or agreed to in writing, software
 * distributed under the License is distributed on an "AS IS" BASIS,
 * WITHOUT WARRANTIES OR CONDITIONS OF ANY KIND, either express or implied.
 * See the License for the specific language governing permissions and
 * limitations under the License.
 */

#ifndef CONFIG_H
#define CONFIG_H

// ================================================================================
// CONFIGURATION
// ================================================================================

// Target Hardware Revision. This should correspond to the revision of the Console
// Adapter schematic multiplied by 10.
#ifndef HW_REV
#define HW_REV 42
#endif
#if HW_REV != 30 && HW_REV != 40 && HW_REV != 41 && HW_REV != 42
#error Unsupported Hardware Revision
#endif

// List of compatible hardware revisions
#ifndef COMPATIBLE_HW_REVS
#if HW_REV == 42
#define COMPATIBLE_HW_REVS { 41 }
#elif HW_REV == 41
#define COMPATIBLE_HW_REVS { 42 }
#else
#define COMPATIBLE_HW_REVS { }
#endif
#endif

// UART for speaking to PDP-11/05 SCL/console.  The RX pin for this UART should be
// connected to the PDP-11's "SERIAL OUT (TTL)" signal (D/04 on the SCL connector),
// while the TX pin should be connected to the "SERIAL IN (TTL)" signal (RR/36).
#define SCL_UART uart0
#if HW_REV >= 40
#define SCL_UART_TX_PIN 16
#define SCL_UART_RX_PIN 1
#else
#define SCL_UART_TX_PIN 12
#define SCL_UART_RX_PIN 13
#endif

// UART for speaking to an auxiliary terminal (if present).  This allows an serial
// terminal to interact with the PDP-11/05 console in parallel to the host USB
// serial device. Comment out AUX_TERM_UART to disable support for an auxiliary terminal.
#define AUX_TERM_UART uart1
#define AUX_TERM_UART_TX_PIN 8
#define AUX_TERM_UART_RX_PIN 9

// Minimum, maximum and default baud rates
//
// The SCL UART in the PDP-11/05 (e.g. an AY-5-1013) supports up to 40000 baud.
#define MIN_BAUD_RATE 110
#define MAX_BAUD_RATE 38400
#define SCL_DEFAULT_BAUD_RATE 9600
#define AUX_DEFAULT_BAUD_RATE 9600

// Output pin for the "CLK IN (TTL)" signal to the PDP-11/05 (T/16 on the SCL connector).
// This pin is used to clock the SCL UART inside the PDP-11, allowing the console adapter
// to control the baud rate.  For this to work, the PDP-11's built-in baud rate generator
// must be disabled by grounding the "CLK DISAB (TTL)" line (N/12 on the SCL connector).
#if HW_REV >= 40
#define SCL_CLOCK_PIN 22
#else
#define SCL_CLOCK_PIN 6
#endif

// SCL detect pin.  This pin is used to detect whether the console adapter is connected
// to the PDP-11/05 SCL port.  The pin is connected to one of the ground pins (e.g. A/01)
// on the SCL connector.  When the console adapter is connected to the PDP-11, the line
// is pulled low; when the console adapter is not connected, an internal pull-up resistor
// pulls the line high.
#if HW_REV >= 40
#define SCL_DETECT_PIN 18
#else
#define SCL_DETECT_PIN 2
#endif

// Input pin for "READER RUN +" signal from PDP-11/05 (F/06 on the SCL connector).
#define READER_RUN_PIN 3

// System Activity LED pin.
#if HW_REV == 40
#define SYS_ACTIVITY_LED_PIN 14
#elif HW_REV >= 41
#define SYS_ACTIVITY_LED_PIN 15
#else
#define SYS_ACTIVITY_LED_PIN PICO_DEFAULT_LED_PIN
#endif

// Tx Activity LED pin.
#if HW_REV == 40
#define TX_ACTIVITY_LED_PIN 15
#elif HW_REV >= 41
#define TX_ACTIVITY_LED_PIN 14
#endif

// Rx Activity LED pin.
#if HW_REV >= 40
#define RX_ACTIVITY_LED_PIN 17
#endif

// Minimum amount of time (in us) that an activity LED should remain either on or off.
#define LED_MIN_STATE_TIME_US 40000

// PWM divisor (integral and fractional components).  These values were chosen to minimize
// error in the SCL clock generator frequency over the range of supported baud rates.
#define PWM_DIVISOR_INT 2
#define PWM_DIVISOR_FRACT 3

// Maximum number of files in the file library
// NOTE: must be <= available selection keys ('0'-'9' and 'a'-'z')
#define MAX_FILES 36

// Maximum file name length
#define MAX_FILE_NAME_LEN 32

// Input character to invoke the menu mode while in terminal mode
#define MENU_KEY '\036' // Ctrl+^

// Maximum size of an uploaded file
#define MAX_UPLOAD_FILE_SIZE (64*1024)

// Width of the paper tape reader progress bar
#define PROGRESS_BAR_WIDTH 20

// Prefix identifying a request for user input
#define INPUT_PROMPT ">>> "

// Prefix identifying menu titles or other notable UI output
#define TITLE_PREFIX "*** "

#endif // CONFIG_H

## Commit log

2024-09-07 Initial version
    -- Initial working version of PDP-11/05 Console USB Adapter for the Raspberry
    Pi Pico. All major features have been implemented and tested on prototype
    hardware with the exception of the READER RUN interface.
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2025-01-16 Schematic and PCB design files
    [pdp1105-console-adapter-v2.kicad_pcb, pdp1105-console-adapter-v2.kicad_sch]
2025-03-16 Reorganize PCB design files
    [pdp1105-console-adapter-v2.kicad_pcb, pdp1105-console-adapter-v2.kicad_sch]
2025-03-16 Initial version of Rev 4 schematic
    -- Added status LEDs
    -- Changed Aux port connector to board-mounted DE9
    -- Added mounting hole components
    [pdp1105-console-adapter-v2.kicad_pcb, pdp1105-console-adapter-v2.kicad_sch]
2025-03-16 Initial version of Rev 4 PCB
    -- New PCB board outline
    -- Basic placement of major components: Pico, SCL connector, DE9, LEDs and
    mounting holes.
    -- No other components placed. No traces routed.
    [pdp1105-console-adapter-v2.kicad_pcb]
2025-03-16 Additional work on menu mode
    -- Added code to listen for multi-character menu key sequences and enter menu mode
    when detected. Currently the code has sequences for TVI-912, TVI-920, VT100 and
    ANSI/VT220+ terminals.
    -- Added skeletal file load and upload modes.
    -- Discarded old MenuKeyMonitor class.
2025-03-16 More work on menu mode
    -- Backtracked on use of multi-character key sequence for menu mode. Menu mode
    now entered using Ctrl+^.
    -- Introduced I/O helper functions to make interactions with host terminal and
    UARTs more readable.
2025-03-16 Major code restructuring
    -- Major modes are now synchronous, rather than being driven from a central loop
    -- Code for initializing and interacting with host terminal, SCL UART and Aux Terminal UART re-organized into separate helper classes
    -- main() function significantly simplified
    -- ConsoleAdapter.h setup as master header for all source files
    -- Load File Mode renamed to Load Data Mode
    -- Stub code introduced for simulating paper tape reader
2025-03-16 More major changes
    -- Introduced Port base class and made port objects virtual. Create global
    objects for the three ports: Host USB, Aux terminal and SCL. Revised all
    other code to use these objects.
    -- Revised Menu Mode code to present UI on the port that the menu character
    was received on (Host USB or Aux terminal). This choice then follows through
    to all other modes that have UI (e.g. Load Data Mode).
    -- Modified Load Data Mode to issue a final set address (L) command with the
    start address of the file being loaded (if applicable). This makes it easy
    to issue a start command (S) to run the just loaded program.
    -- Created BuildInFileSet class for accessing paper tape files that a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
    [AuxPort.cpp, Config.h]
2025-03-16 Paper tape file set builder tool
    -- Command line tool to build a paper tape file set that can be directly flashed
    onto the Console Adapter. The tool takes a list of paper tape files and encodes
    them into a UF2 file that can be dragged to the Pico’s USB filesystem or flashed
    with the picotool.
2025-03-16 Support for loading simple data files (files that aren’t Absolute Loader files or otherwise special).
2025-03-16 Absolute Loader support
    -- Support for mounting a built-in paper tape image of the Absolute Loader
    -- Support for loading the Absolute Loader into memory using the M9301/M9312
    console.
    -- Minor clean-ups to Bootstrap Loader code.
2025-03-16 Work on M9301/M9312 controller
    -- Implemented new mechanism for prompt synchronization based on using a
    sync character.
    -- Added validation of characters received from the M9301/M9312 console
    and error handling for unexpected characters.
    -- Minor changes to timer handling.
2025-03-18 Restructured Menu Mode code
    -- Created general mechanism for rendering menus and prompting for a
    selection.
    -- Created general mechanism for selecting files
    -- Rearranged file menu presentation and added support for case where
    no user-installed files are present
2025-03-20 Use interrupts instead of polling to detect a change in the READER RUN signal.
2025-03-20 Added support for external activity LEDs
    -- Implemented support for external Tx and Rx activity LEDs. These signal when
    the SCL port is transmitting or receiving characters.
    -- Implemented support for an extern system activity LED. This serves as both
    a power indicator and a signal of activity on the USB host or Aux ports. The
    Pico onboard LED mirrors the state of this LED.
    The GPIO numbers assigned to the new external LEDs are provisional until the new
    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
2025-04-02 Completed layout and routing for revision 4 PCB
    -- NOTE: Pico pin assignments were altered from revision 3 board to simplify routing
    [pdp1105-console-adapter-v2.kicad_pcb, pdp1105-console-adapter-v2.kicad_sch]
2025-04-04 Updates to rev 4 PCB layout
    -- Moved SMT components to back side of PCB to facilitate rework when Pico
    is soldered in place.
    [pdp1105-console-adapter-v2.kicad_pcb]
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2025-04-05 Removed unnecessary execute permissions
    [pdp1105-console-adapter-v2.kicad_pcb, pdp1105-console-adapter-v2.kicad_sch]
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2025-04-12 Revision 4.1 Schematic and PCB Design
    -- Switch to female DE9 connector for Aux port.
    -- Added solder jumpers to select between DTE and DCE configuration for Aux
    port. Default is set to DCE.
    -- Revised LED component layout to allow for copper keep-out area under
    Pico W antenna.
    -- Added copper ground fill on PCB backside.
    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
    [pdp1105-console-adapter-v2.kicad_pcb, pdp1105-console-adapter-v2.kicad_sch]
2025-04-12 Firmware support for rev 4.1 PCB
    -- Swap GPIOs for System Status and Tx LEDs
    -- Generalized HW_REV #define to support minor revisions
    [Config.h]
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2025-04-25 Revision 4.2 Schematic and PCB Design
    -- Fixed bug in schematic that resulted in the AUX port defaulting to DTE
    configuration instead of DCE.
    -- Fixed bug in PCB silkscreen that mislabeled the jumper configuration for
    choosing AUX port DTE vs. DCE configuration.
    Note that revision 4.2 is firmware compatible with revision 4.1.
    [pdp1105-console-adapter-v2.kicad_pcb, pdp1105-console-adapter-v2.kicad_sch]
2025-06-11 Various changes
    -- Renamed files and updated code and documentation to consistently use the
    term "file library" to refer to files stored in flash.
    -- Fixed bug in menu mode that displayed incorrect selector character when
    file library contained more than 10 files.
    -- Update default file library image to include PAL-11 and associated paper
    tape images.
    -- Removed unnecessary XXDP tests from the default file library.
    -- Minor editorial changes to README.
    [Config.h, main.cpp]
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2025-06-15 Updated user manual with picture showing correct orientation of SCL cable
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2025-07-13 Initial case designs for standalone and direct attach models
    [PDP 1105 Direct Attach 9.6mm 2x40 Spacer.stl, PDP 1105 Direct Attach Case Bottom.stl, PDP 1105 Direct Attach Case Top.stl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]
2025-07-13 Reorg case design files
    [pdp1105-console-adapter-v2-board-outline.dxf, pdp1105-console-adapter-v2-case-mock.step, pdp1105-console-adapter-v2-direct-attach-case-bottom.stl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]
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2026-10-05 Transparent Mode
    -- Added new mode of operation in which all characters, including
    the menu key, are passed to the SCL port without modification.
    Because the menu key is disabled, it is not possible to access the
    adapter menus while in transparent mode. The adapter automatically
    exits transparent mode when it detects the PDP-11 has been powered
    off, or when the adapter itself is rebooted.
    -- Added mechanism to detect the power state of the PDP-11/05. The
    mechanism works by monitoring the SERIAL OUT (TTL) line from the
    SCL port (the RX line on the adapter’s UART). If the SERIAL OUT line
    stays low (0V) for an extended period of time (100ms), the adapter
    concludes that the PDP-11 is powered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
    [SCLPort.cpp]

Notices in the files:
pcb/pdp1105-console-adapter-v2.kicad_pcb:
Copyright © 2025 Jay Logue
